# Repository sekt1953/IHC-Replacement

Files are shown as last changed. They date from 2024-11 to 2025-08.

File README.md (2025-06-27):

# IHC-Replacement

Her laver jeg en erstatning for mit LK IHC system

Jeg kan ikke længere få reserve dele til mit IHC system som styrer alt lys i huset. 
Jeg har i forevejen et Home Assistant project igang, så nu vil jeg fremstille PCB som kan virke som interface mellem min El installation Og Home Assistant.

## Fritzing

* I/O Ver. 0.22 FritzingFab
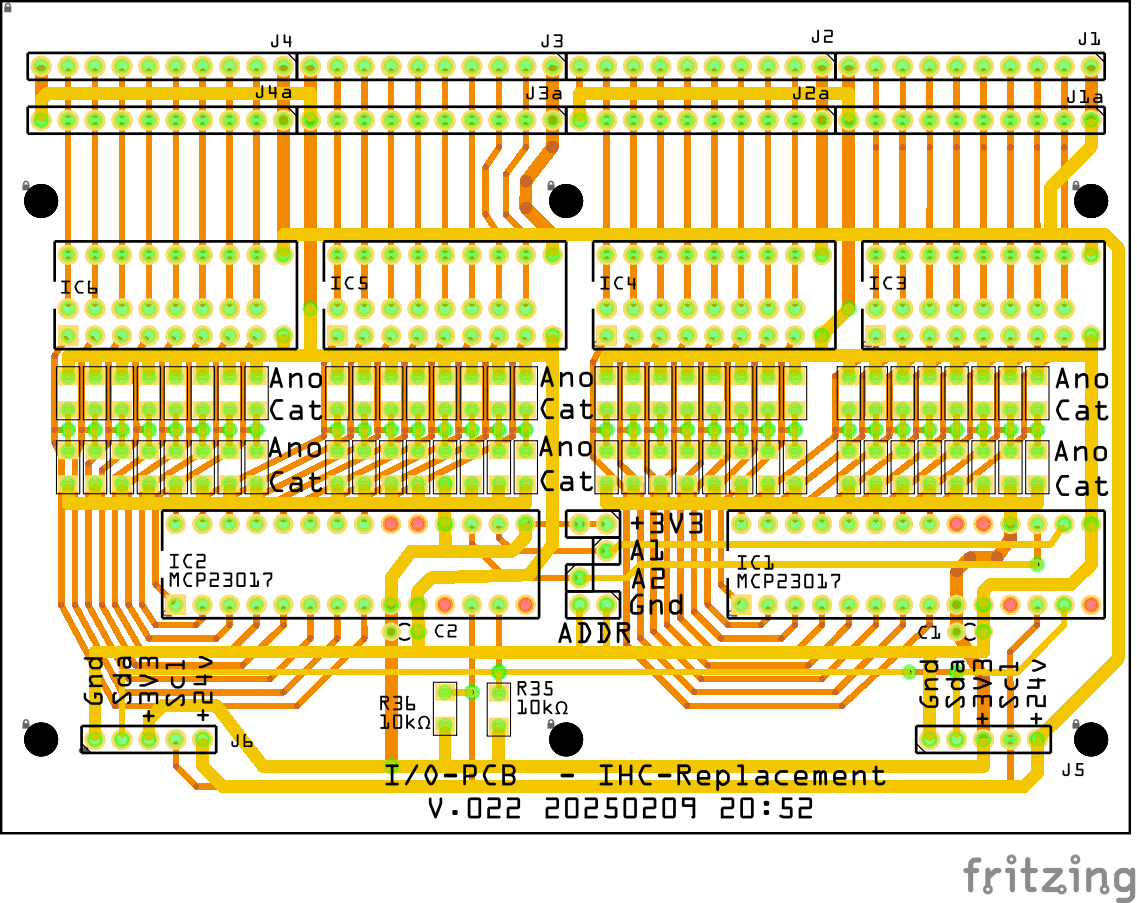
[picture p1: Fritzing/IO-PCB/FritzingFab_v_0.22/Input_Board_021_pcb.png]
PCB 0.22
  * 
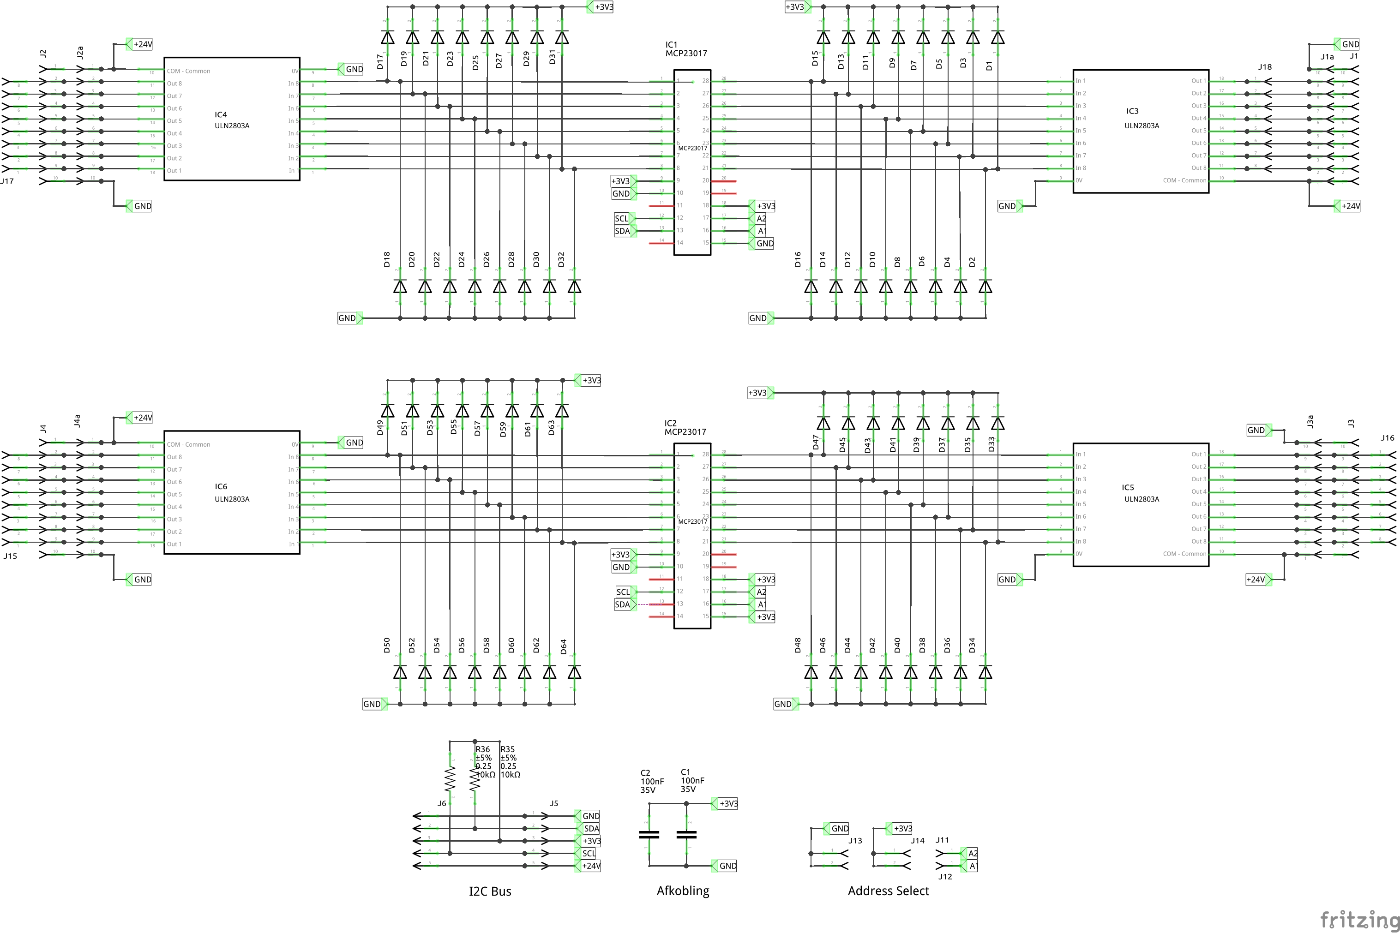
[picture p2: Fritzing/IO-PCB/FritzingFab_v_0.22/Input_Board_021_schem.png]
schem 0.22
  * 
  * [fzz 0.22](./Fritzing/IO-PCB/FritzingFab_v_0.22/Input_Board_022.fzz)
* I/O Ver. 0.41 
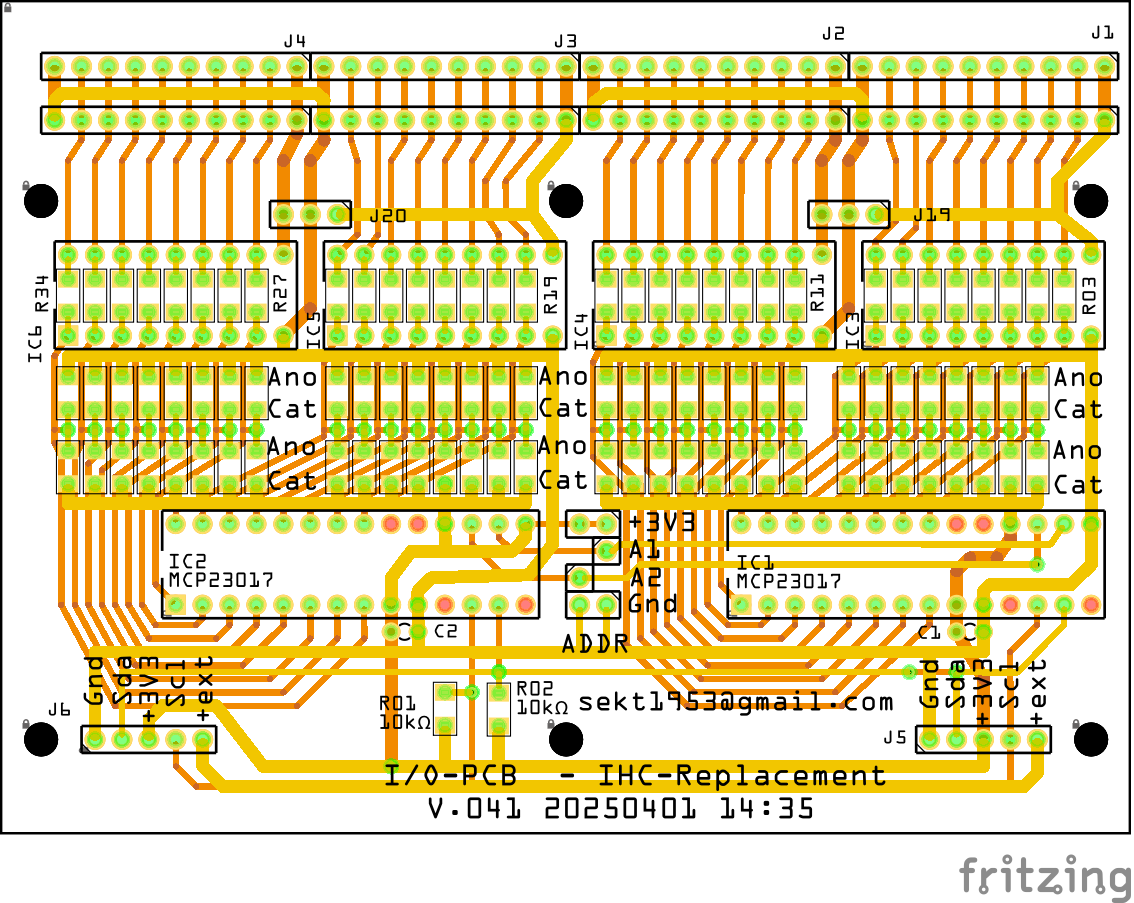
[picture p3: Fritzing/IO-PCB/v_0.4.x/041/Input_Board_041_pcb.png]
PCB 0.41
  * 
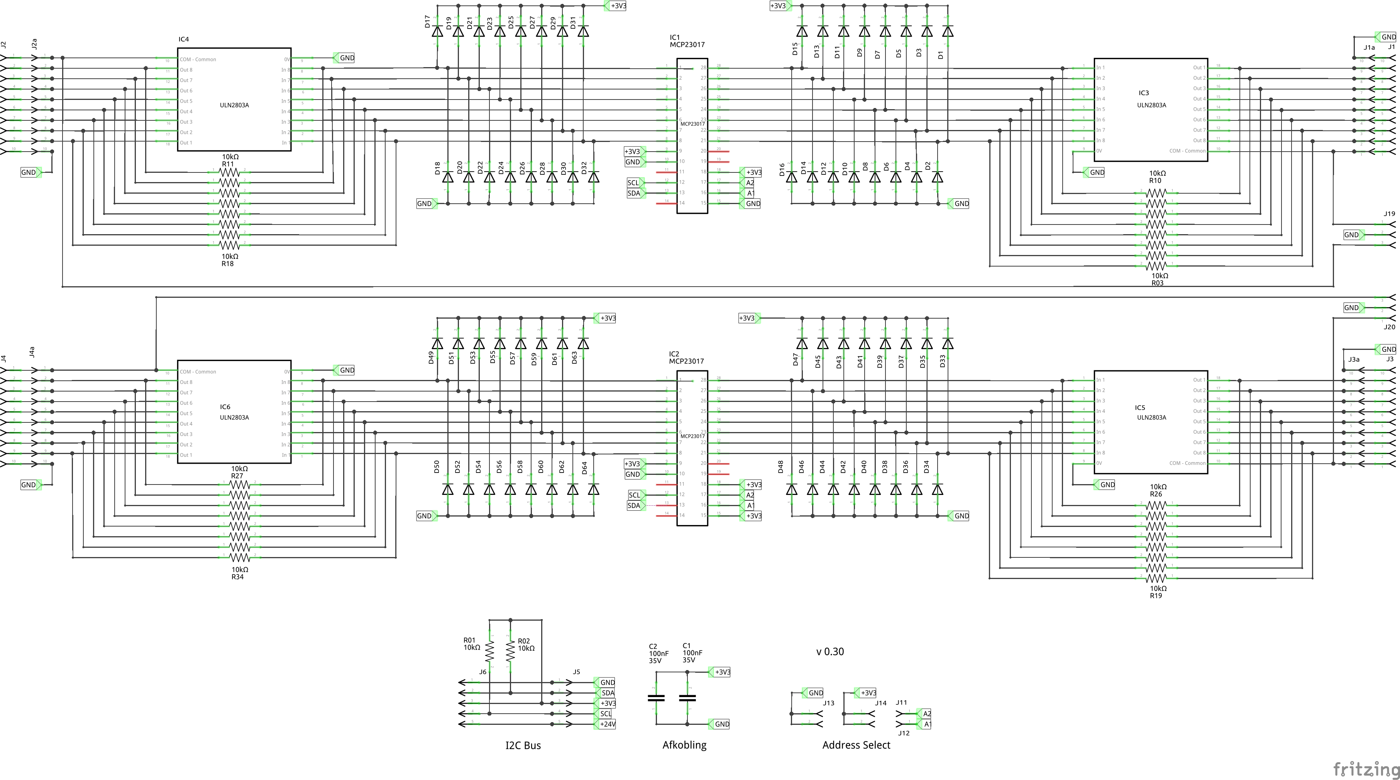
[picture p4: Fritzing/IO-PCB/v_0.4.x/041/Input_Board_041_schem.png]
schem 0.41
  * 
  * [Fritzing file version 0.41](./Fritzing/IO-PCB/v_0.4.x/041/Input_Board_041.fzz)

### Bill of Materials

* I/O-PCB IHC-Replacement v.041 20250401 17:51
  * Fælleds for Input og Output config
    * 1 stk PCB, I/O-PCB IHC-Replacement v.040
    * 2 stk MCP20017-E/SP 16-bit
    * 2 stk Ceramic Capacitor 100nF
    * 2 stk 10kΩ Resistor SMD 1206
    * 2 stk 5 pol connector for I2C bus, vinkel MOD 2,54mm
    * 4 stk 10 pol connector for Input / Output, KF141R-10P MOD 2,54mm
    * 2 stk jumper for I2C addr. settings
    * 1 Tube SMD Solder Paste Flux Low Temperature 138°C 30g
  * Matrialer for Input PCB
    * 64 stk 1N4148 SMD 1206
    * 32 stk 10kΩ Resistor SMD 1206
  * Matrialer for Output PCB
    * 4 stk ULN2803A
    * 2 stk 3pol connector for nødbelysning MOD 2,54mm

## FreeCAD

* [DINBox_200 FreeCAD-file](./FreeCAD/DinBox/DinBox_200/DinBox_200.FCStd)
* [DinBox_200_Top
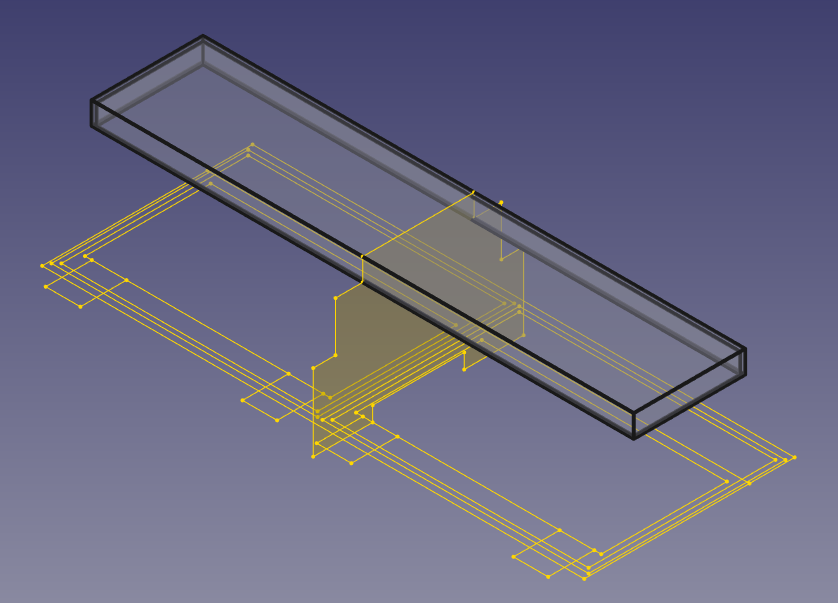
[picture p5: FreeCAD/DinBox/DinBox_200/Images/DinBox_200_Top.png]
DinBox_200_Top
  * 
* DinBox_200_Body
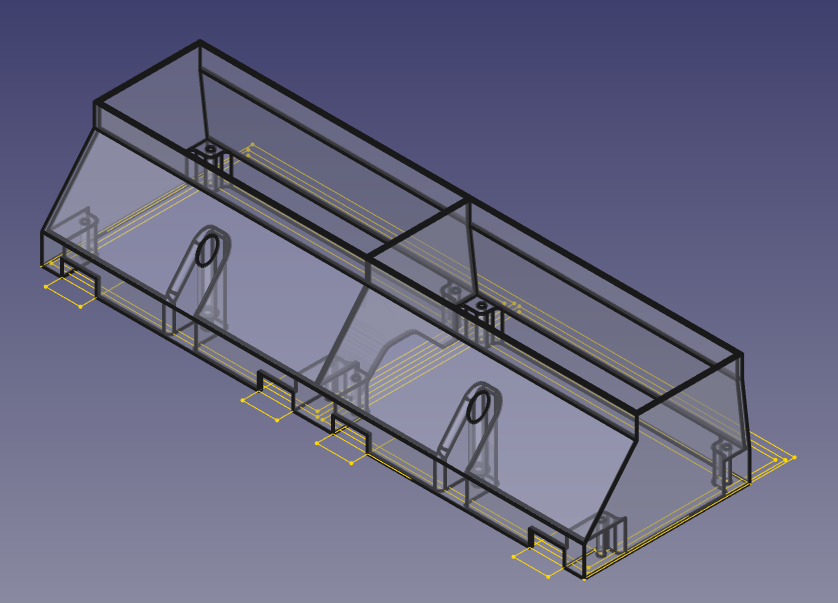
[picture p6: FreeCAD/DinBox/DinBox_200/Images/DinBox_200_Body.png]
DinBox_200_Body
  * 
* DinBox_200_BodyYZ
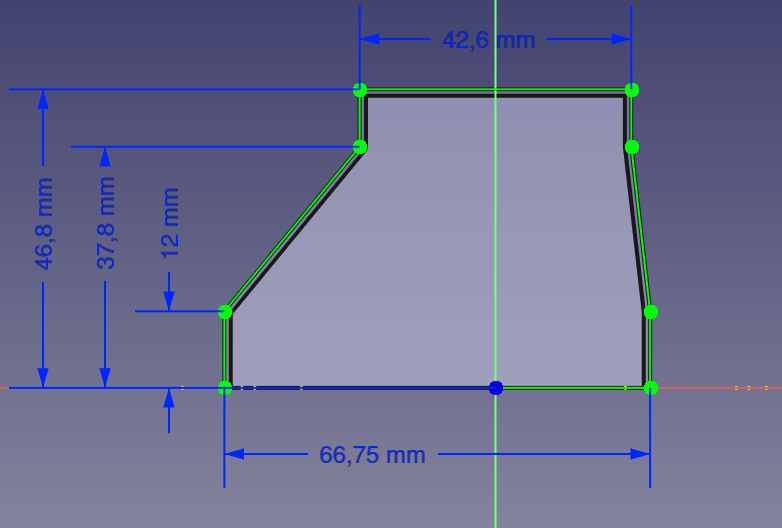
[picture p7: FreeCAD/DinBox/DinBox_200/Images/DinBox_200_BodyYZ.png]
DinBox_200_BodyYZ
  * 
* DinBox_200_BaseXY
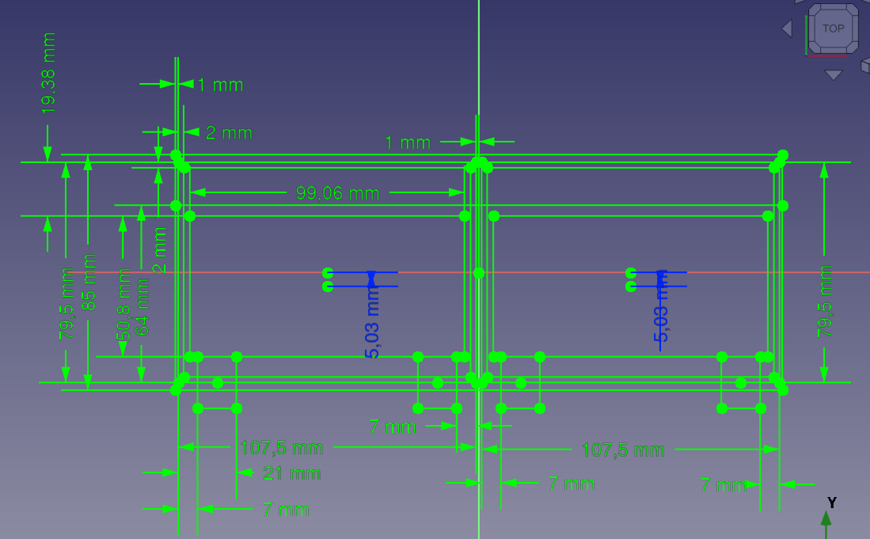
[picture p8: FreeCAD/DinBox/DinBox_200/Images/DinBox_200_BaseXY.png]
DinBox_200_BaseXY
  * 
* DinBox_200_BaseYZ
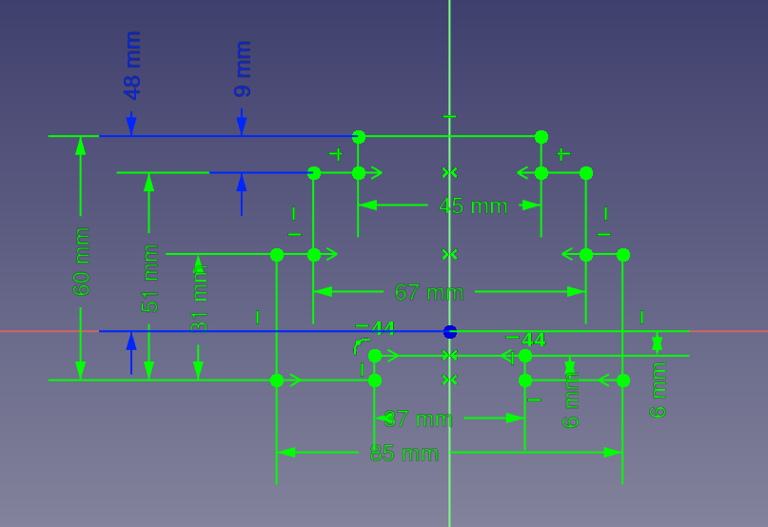
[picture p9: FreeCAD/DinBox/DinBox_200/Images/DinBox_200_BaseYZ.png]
DinBox_200_BaseYZ
  * 
* DINBox_200 3mf-file
  * [DINBox_200 Top 3mf-file](./FreeCAD/DinBox/DinBox_200/DinBox_200-Top.3mf)
  * [DINBox_200 Body 3mf-file](./FreeCAD/DinBox/DinBox_200/DinBox_200-Body002.3mf)

## Home Assistant

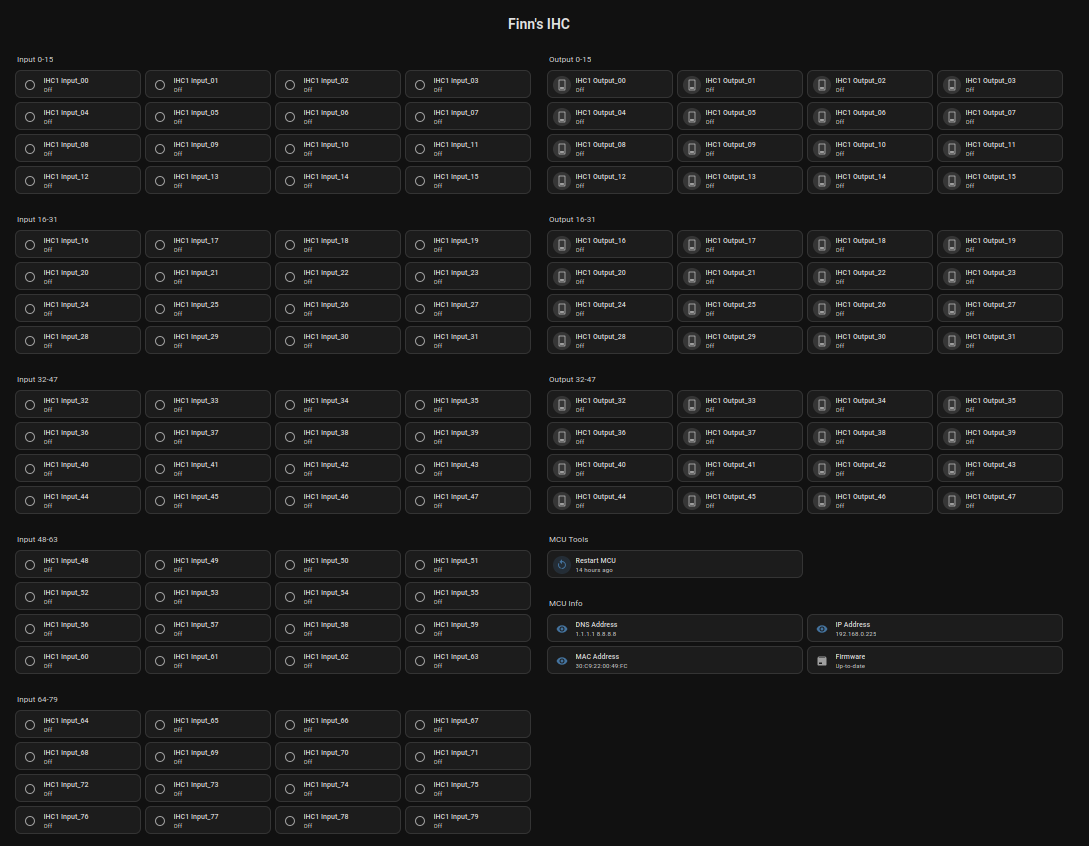
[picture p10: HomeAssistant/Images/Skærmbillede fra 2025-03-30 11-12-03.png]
Skærmbilled
* 
  * [Raw configuration Finn's IHC](./HomeAssistant/RawConfigurationFinnsIHC.yaml)

## ESPHome

### YAML-files

* Opsætningen her er for:
  * 48 output for relæer type [Finder](./DataSheet/Finder/Finder.md)
  * 80 input med transient beskyttelse.
* MCU: **OLIMEX ESP32-POE-ISO-16MB**
  * [Manual](./DataSheet/Olimex/ESP32-POE-user-manual.pdf)
  * [Pinout](./DataSheet/Olimex/ESP32-POE-ISO-GPIO.png)
  * **Basic file**
    * [ihc1.yaml](./ESPHome/ihc1.yaml)
  * ESP32 
    * [.olimex-esp32-poe.yaml](./ESPHome/Includes/ESP32/.olimex-esp32-poe.yaml)
  * MCP23017
    * [.mcp23017_ids.yaml](./ESPHome/Includes/MCP23017/.mcp23017_ids.yaml)
    * [.mcp23017_input.yaml](./ESPHome/Includes/MCP23017/.mcp23017_input.yaml)
    * [.mcp23017_output.yaml](./ESPHome/Includes/MCP23017/.mcp23017_output.yaml)
* Home Assistant
  * Automation
    * [LK-PushButton-Pressed](./HomeAssistant/LK-Button/LK-PushBUtton-Pressed.yaml)
      * [Long and short button pressing automation](https://community.home-assistant.io/t/long-and-short-button-pressing-automation/466916/6)
      * Array

Template editor:

```code
{% set my_test_json = { "items": ["car","horse"] } %}
* Items:{% for item in my_test_json["items"] %}
 * {{item}}
{%- endfor %}

* Items[0]:
* {{my_test_json["items"][0]}}

* Items[1]:
* {{my_test_json["items"][1]}}
```

Result:

```code
* Items:
  * car
  * horse

* Items[0]:
  * car

* Items[1]:
  * horse
```

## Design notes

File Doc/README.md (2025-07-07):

# Installations dokumentation

## Home Assistant & ESPHome

* [Home Assistant & ESPHome instllation](./LK_taster_Pir_Røgdetectors_kabling.md)
  * [Input - LK taster, Pir & Røgdetector's kabling](./LK_taster_Pir_Røgdetectors_kabling.md#input)
  * [Output - LK taster, Pir & Røgdetector's kabling](./LK_taster_Pir_Røgdetectors_kabling.md#output)

## ESP32

* Olimex
  * [ESP32-POE-ISO-16MB](https://www.olimex.com/Products/IoT/ESP32/ESP32-POE-ISO/open-source-hardware)
  * [ESP32-POE-ISO user manual](https://github.com/OLIMEX/ESP32-POE/blob/master/DOCUMENTS/ESP32-POE-user-manual.pdf)
  * [ESP32-POE-ISO latest schematic in PDF format](https://github.com/OLIMEX/ESP32-POE-ISO/blob/master/HARDWARE/ESP32-PoE-ISO-Rev.L/ESP32-PoE-ISO_Rev_L.pdf)
  * [ESP32-POE-ISO GPIO map](https://www.olimex.com/Products/IoT/ESP32/ESP32-POE-ISO/resources/ESP32-POE-ISO-GPIO.png)

## Zigbee

* [SilverCrest Zigbee Gateway](https://zigbee.blakadder.com/Lidl_TYGWZ-01.html)

## Tailscale

* Videoer
  * [Tailscale](https://www.youtube.com/@Tailscale)
    * [How to get started with Tailscale in under 10 minutes](https://youtu.be/sPdvyR7bLqI)
    * [Remotely access Home Assistant via Tailscale for free!](https://youtu.be/vDxmtRByXDY)
    * [Remotely access and share your self-hosted services](https://youtu.be/Vt4PDUXB_fg "Tailscale")
  * [Tailscale Explained](https://www.youtube.com/playlist?list=PLbKN2w7aG8ELRhEl3b-skkHxz6jcKLuFT)
    * [Serve and Funnel](https://youtu.be/MpxmfpCl20c?list=PLbKN2w7aG8ELRhEl3b-skkHxz6jcKLuFT)
    * [What is Tailscale SSH?](https://youtu.be/08clF9srJ2k?list=PLbKN2w7aG8ELRhEl3b-skkHxz6jcKLuFT)
      * [Tailscale SSH](https://tailscale.com/kb/1193/tailscale-ssh)
    * [Subnet Routers](https://youtu.be/UmVMaymH1-s?list=PLbKN2w7aG8ELRhEl3b-skkHxz6jcKLuFT)
    * [ACLs 101 - An Introduction to Access Control Lists](https://youtu.be/Jn8_Sh4r8d4?list=PLbKN2w7aG8ELRhEl3b-skkHxz6jcKLuFT)
      * [Manage permissions using ACLs](https://tailscale.com/kb/1018/acls)
    * [Exit Nodes](https://youtu.be/Ad7D2pkFNdA?list=PLbKN2w7aG8ELRhEl3b-skkHxz6jcKLuFT)
    * [App Connectors - Split DNS for any website on your tailnet ](https://youtu.be/z1vBMMQzCEk?list=PLbKN2w7aG8ELRhEl3b-skkHxz6jcKLuFT)

## IHC (gammel installation)

* [IHC (gammel installation)](./IHC_gammel%20installation.md)

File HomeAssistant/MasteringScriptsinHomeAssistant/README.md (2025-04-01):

# Mastering Scripts in Home Assistant

## Kilder:

* [Smart Home Junkie](https://www.youtube.com/@SmartHomeJunkie)
  * [Mastering Scripts in Home Assistant: A Comprehensive Guide](https://youtu.be/vD_xckjQxRk)
* [SlackerLabs](https://www.youtube.com/@SlackerLabs)
  * [Mastering Home Assistant Templates: Intro to Date and Time](https://youtu.be/2WIi5xq0iHI?list=PLJAP47iycH2IV8m5RnMF4hmZ_mVb7vgv_)

## Use Case 1: Send a fixed message to your phone

## Use Case 2: [Send a custom message to your phone using fields in scripts](https://www.youtube.com/watch?v=vD_xckjQxRk&t=219s)

* Script: "Notify: Persistent"

```code
sequence:
  - action: persistent_notification.create
    metadata: {}
    data:
      message: "{{message}}"
      title: "{{title}}"
alias: "Notify: Persistent"
description: 
fields:
  title:
    selector:
      text: null
    name: title
    description: Enter a title for your notification
    required: true
  message:
    selector:
      text: null
    name: message
    description: Enter a message for your notification
    required: true
```

* Automation: "Notify: Send a custom message"

```code
alias: "Notify: Send a custom message"
description: ""
triggers:
  - trigger: state
    entity_id:
      - binary_sensor.ihc1_input_00
      - binary_sensor.ihc1_input_02
    to: "on"
conditions: []
actions:
  - action: script.notify_persistent
    data:
      title: This is a custom title
      message: and this is the custom message
mode: single

```

## Use Case 3: [Send a custom weather condition to your phone using response variables in scripts](https://www.youtube.com/watch?v=vD_xckjQxRk&t=454s)

* Script: "Weather: get custom weather condition"

```code
alias: "Weather: get custom weather condition"
variables:
  weather_condition: |
    {% set temperature = state_attr("weather.forecast_hjem","temperature") %}
    {% if (temperature < 5) %}
      {% set condition = "Cold" %}
    {% elif (temperature >= 5 and temperature <= 15 ) %}
      {% set condition = "Chilly" %}
    {% elif (temperature >= 15 and temperature <= 20 ) %}
      {% set condition = "Comfortable" %}
    {% elif (temperature >= 20 and temperature <= 30 ) %}
      {% set condition = "Warm" %}
    {% elif (temperature >= 30 ) %}
      {% set condition = "To Warm !!" %}
    {% endif %}
    {{ {'value': condition} }}
sequence:
  - stop: End
    response_variable: weather_condition
description: ""
```

* Automation: ""

```code
alias: "Notify: Send a custom message"
description: ""
triggers:
  - trigger: state
    entity_id:
      - binary_sensor.ihc1_input_00
      - binary_sensor.ihc1_input_02
      - switch.ihc1_output_00
    to: "on"
    for:
      hours: 0
      minutes: 0
      seconds: 1
conditions: []
actions:
  - action: script.weather_get_custom_weather_condition
    data: {}
    response_variable: result
  - action: script.notify_persistent
    data:
      message: The weather is {{ result.value }}
      title: Weather Condition
mode: single

```

## Mastering Home Assistant Templates: Intro to Date and Time

[Mastering Home Assistant Templates: Intro to Date and Time](https://www.youtube.com/watch?v=2WIi5xq0iHI&list=PLJAP47iycH2IV8m5RnMF4hmZ_mVb7vgv_&index=3&t=1707s)

```code
{{ states.switch.ihc1_output_00.last_updated }}
{{ states.switch.ihc1_output_00.last_changed }}

{{ as_datetime('2024-03-20 12:04:20') }}
{{ as_timestamp('2024-03-20 12:04:20') }}
{{ as_timestamp('2024-03-20') }}

**
{{ 
  as_timestamp(now()) -
  as_timestamp(states.switch.ihc1_output_00.last_changed)
}}
```

## Call a Script from an Automation, and access Trigger/Entity inside the Script

### Kilde: [Call a Script from an Automation, and access Trigger/Entity inside the Script](https://community.home-assistant.io/t/call-a-script-from-an-automation-and-access-trigger-entity-inside-the-script/603114/2)

### You need to pass the trigger variables to the script: https://www.home-assistant.io/integrations/script/#passing-variables-to-scripts

* Automation:

```code
action:
  - service: script.notify_level1_user
    data:
      trig_id: "{{ trigger.entity_id }}"
      trig_val: "{{ trigger.to_state.state }}"
```

* And in the script

```code
sequence:
  - service: notify.level1_users # or whatever your notification service is called
    data:
      message: " The sensor {{ trig_id }} has the value {{ trig_val }}"
```
### Developer tools

* Kilde:
  * [Extract a nested array value in JSON](https://community.home-assistant.io/t/solved-extract-a-nested-array-value-in-json/173906/2)

#### Template editor

```yaml
"meta" : [ { 
    "publisher" : "Environment Agency" ,
    "licence" : "http://www.nationalarchives.gov.uk/doc/open-government-licence/version/3/" ,
    "documentation" : "http://environment.data.gov.uk/flood-monitoring/doc/reference" ,
    "version" : "0.9" ,
    "comment" : "Status: Beta service" ,
    "hasFormat" : [ { "csv" : "http://environment.data.gov.uk/flood-monitoring/id/stations/2077/readings.csv?latest", "rdf" : "http://environment.data.gov.uk/flood-monitoring/id/stations/2077/readings.rdf?latest" } ]
  } ],
  "items" : [ { 
    "@id" : "http://environment.data.gov.uk/flood-monitoring/data/readings/2077-level-stage-i-15_min-mASD/2020-02-23T11-00-00Z" ,
    "dateTime" : "2020-02-23T11:00:00Z" ,
    "measure" : "http://environment.data.gov.uk/flood-monitoring/id/measures/2077-level-stage-i-15_min-mASD" ,
    "value" : 3.518
  }
   ]
} %}
meta:
{{ value_json['meta'][0].publisher }}
{{ value_json['meta'][0].licence }}
{{ value_json['meta'][0].documentation }}
{{ value_json['meta'][0].version }}
{{ value_json['meta'][0].comment }}
{{ value_json['meta'][0].hasFormat[0].csv }}
{{ value_json['meta'][0].hasFormat[0].rdf }}

Items:
{{ value_json['items'][0].id }}
{{ value_json['items'][0].dateTime }}
{{ value_json['items'][0].measure }}
{{ value_json['items'][0].value }}
```

#### Result

```yaml
meta:
Environment Agency
http://www.nationalarchives.gov.uk/doc/open-government-licence/version/3/
http://environment.data.gov.uk/flood-monitoring/doc/reference
0.9
Status: Beta service
http://environment.data.gov.uk/flood-monitoring/id/stations/2077/readings.csv?latest
http://environment.data.gov.uk/flood-monitoring/id/stations/2077/readings.rdf?latest

Items:
http://environment.data.gov.uk/flood-monitoring/data/readings/2077-level-stage-i-15_min-mASD/2020-02-23T11-00-00Z
2020-02-23T11:00:00Z
http://environment.data.gov.uk/flood-monitoring/id/measures/2077-level-stage-i-15_min-mASD
3.518
```

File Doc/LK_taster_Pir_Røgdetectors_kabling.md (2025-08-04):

# LK taster, Pir & Røgdetector's kabling

## Input

|Kabel|Lokalitet|Placering____|Komponent|Terminal|Farve|I/O Interface|I2C-Addr|Kort_Tryk|Langt_Tryk||
|:---:|:---|:---|:---|:---:|:---|:---|:---|:---|:---|:---|
|1|Lille Bad|Ved dør|Tryk 4 tast|GND|Blå|GND|||
|1|Lille Bad|Ved dør|Tryk 4 tast|Tryk ØV|Sort|Input_00|0x23.0|Output_34|Output_34||
|1|Lille Bad|Ved dør|Tryk 4 tast|Tryk ØH|Grøn|Input_01|0x23.1|Output_05|||
|1|Lille Bad|Ved dør|Tryk 4 tast|Tryk NV|Violet|Input_02|0x23.2|Output_32|||
|1|Lille Bad|Ved dør|Tryk 4 tast|Tryk NH|Brun|Input_03|0x23.3|Output_06|||
||||||||||
|2|Kontor|Ved dør|Tryk 4 tast|GND|Blå|GND|||
|2|Kontor|Ved dør|Tryk 4 tast|Tryk ØV|Sort|Input_04|0x23.4|Output_26|Output_26||
|2|Kontor|Ved dør|Tryk 4 tast|Tryk ØH|Grøn|Input_05|0x23.5||||
|2|Kontor|Ved dør|Tryk 4 tast|Tryk NV|Violet|Input_06|0x23.6||||
|2|Kontor|Ved dør|Tryk 4 tast|Tryk NH|Brun|Input_07|0x23.7||||
||||||||||
|3|Værelse|Ved dør|Tryk 4 tast|GND|Blå|GND|||
|3|Værelse|Ved dør|Tryk 4 tast|Tryk ØV|Sort|Input_08|0x23.8|Output_27|Output_27||
|3|Værelse|Ved dør|Tryk 4 tast|Tryk ØH|Grøn|Input_09|0x23.9||
|3|Værelse|Ved dør|Tryk 4 tast|Tryk NV|Violet|Input_10|0x23.10||
|3|Værelse|Ved dør|Tryk 4 tast|Tryk NH|Brun|Input_11|0x23.11||
||||||||||
|9|Soveværelse|Ved seng V|Tryk 4 tast|GND|Blå|GND|||
|9|Soveværelse|Ved seng V|Tryk 4 tast|Tryk ØV|Sort|Input_12|0x23.12||||
|9|Soveværelse|Ved seng V|Tryk 4 tast|Tryk ØH|Grøn|Input_13|0x23.13|Output_12|||
|9|Soveværelse|Ved seng V|Tryk 4 tast|Tryk NV|Violet|Input_14|0x23.14|Output_17|||
|9|Soveværelse|Ved seng V|Tryk 4 tast|Tryk NH|Brun|Input_15|0x23.15||||
||||||||||
||||||||||
|4|Garage|Bryggers dør|Tryk 6 tast|GND|Blå|GND|||||
|4|Garage|Bryggers dør|Tryk 6 tast|Tryk ØV|Sort|Input_16|0x24.0||||
|4|Garage|Bryggers dør|Tryk 6 tast|Tryk ØH|Grøn|Input_17|0x24.1||||
|4|Garage|Bryggers dør|Tryk 6 tast|Tryk MV|Violet|Input_18|0x24.2||||
|4|Garage|Bryggers dør|Tryk 6 tast|Tryk MH|Brun|Input_19|0x24.3||
|4|Garage|Bryggers dør|Tryk 6 tast|Tryk NV|Rød|Input_20|0x24.4||
|4|Garage|Bryggers dør|Tryk 6 tast|Tryk NH|Grå|Input_21|0x24.5||
||||||||||
|5|Køkken|Bryggers dør|Tryk 6 tast|GND|Blå|GND|||
|5|Køkken|Bryggers dør|Tryk 6 tast|Tryk ØV|Sort|Input_22|0x24.6||
|5|Køkken|Bryggers dør|Tryk 6 tast|Tryk ØH|Grøn|Input_23|0x24.7||
|5|Køkken|Bryggers dør|Tryk 6 tast|Tryk MV|Violet|Input_24|0x24.8||
|5|Køkken|Bryggers dør|Tryk 6 tast|Tryk MH|Brun|Input_25|0x24.9||
|5|Køkken|Bryggers dør|Tryk 6 tast|Tryk NV|Rød|Input_26|0x24.10||
|5|Køkken|Bryggers dør|Tryk 6 tast|Tryk NH|Grå|Input_27|0x24.11||
||||||||||
||||||||||
|6|Stue|På væg|Tryk 6 tast|GND|Blå|GND|||
|6|Stue|På væg|Tryk 6 tast|Tryk ØV|Sort|Input_32|0x25.0||
|6|Stue|På væg|Tryk 6 tast|Tryk ØH|Grøn|Input_33|0x25.1||
|6|Stue|På væg|Tryk 6 tast|Tryk MV|Violet|Input_34|0x25.2||
|6|Stue|På væg|Tryk 6 tast|Tryk MH|Brun|Input_35|0x25.3||
|6|Stue|På væg|Tryk 6 tast|Tryk NV|Rød|Input_36|0x25.4||
|6|Stue|På væg|Tryk 6 tast|Tryk NH|Grå|Input_37|0x25.5||
||||||||||
|7|Entré|Køkken dør|Tryk 6 tast|GND|Blå|GND|||
|7|Entré|Køkken dør|Tryk 6 tast|Tryk ØV|Sort|Input_38|0x25.6||
|7|Entré|Køkken dør|Tryk 6 tast|Tryk ØH|Grøn|Input_39|0x25.7||
|7|Entré|Køkken dør|Tryk 6 tast|Tryk MV|Violet|Input_40|0x25.8||
|7|Entré|Køkken dør|Tryk 6 tast|Tryk MH|Brun|Input_41|0x25.9||
|7|Entré|Køkken dør|Tryk 6 tast|Tryk NV|Rød|Input_42|0x25.10||
|7|Entré|Køkken dør|Tryk 6 tast|Tryk NH||Input_43|0x25.11||
||||||||||
|10|Entré|Yderdør|Tryk 4 tast|GND|Blå|GND|||
|10|Entré|Yderdør|Tryk 4 tast|Tryk ØV|Sort|Input_44|0x25.12||
|10|Entré|Yderdør|Tryk 4 tast|Tryk ØH|Grøn|Input_45|0x25.13||
|10|Entré|Yderdør|Tryk 4 tast|Tryk NV|Violet|Input_46|0x25.14||
|10|Entré|Yderdør|Tryk 4 tast|Tryk NH||Input_47|0x25.15||
||||||||||
||||||||||
|8|Soveværelse|St. bad|Tryk 6 tast|GND|Blå|GND|||
|8|Soveværelse|St. bad|Tryk 6 tast|Tryk ØV|Sort|Input_48|0x26.0||
|8|Soveværelse|St. bad|Tryk 6 tast|Tryk ØH|Grøn|Input_49|0x26.1||
|8|Soveværelse|St. bad|Tryk 6 tast|Tryk MV|Violet|Input_50|0x26.2||
|8|Soveværelse|St. bad|Tryk 6 tast|Tryk MH|Brun|Input_51|0x26.3||
|8|Soveværelse|St. bad|Tryk 6 tast|Tryk NV|Rød|Input_52|0x26.4||
|8|Soveværelse|St. bad|Tryk 6 tast|Tryk NH|Grå|Input_53|0x26.5||
||||||||||
|11|Køkken|Viktualrum|Tryk 6 tast|GND|Blå|GND|||
|11|Køkken|Viktualrum|Tryk 6 tast|Tryk ØV|Sort|Input_54|0x26.6||
|11|Køkken|Viktualrum|Tryk 6 tast|Tryk ØH|Grøn|Input_55|0x26.7||
|11|Køkken|Viktualrum|Tryk 6 tast|Tryk MV|Violet|Input_56|0x26.8||
|11|Køkken|Viktualrum|Tryk 6 tast|Tryk MH|Brun|Input_57|0x26.9||
|11|Køkken|Viktualrum|Tryk 6 tast|Tryk NV|Rød|Input_58|0x26.10||
|11|Køkken|Viktualrum|Tryk 6 tast|Tryk NH|Grå|Input_59|0x26.11||
||||||||||
|33|Stue|På væg|Pir|Alarm|Sort|Input_60|0x26.12||
||Soveværelse|Ved dør til toilet|Pir|Alarm|Hvid|Input_61|0x26.13||
|31|Bryggers|På væg|Pir|Alarm|Sort|Input_62|0x26.14||
|30|Garage|På væg|Pir|Alarm|Sort|Input_63|0x26.15||
||||||||||
||||||||||
|12|Garage|Yderdør|Tryk 6 tast|GND|Blå|GND|||
|12|Garage|Yderdør|Tryk 6 tast|Tryk ØV|Sort|Input_64|0x27.0||
|12|Garage|Yderdør|Tryk 6 tast|Tryk ØH|Grøn|Input_65|0x27.1||
|12|Garage|Yderdør|Tryk 6 tast|Tryk MV|Violet|Input_66|0x27.2||
|12|Garage|Yderdør|Tryk 6 tast|Tryk MH|Brun|Input_67|0x27.3||
|12|Garage|Yderdør|Tryk 6 tast|Tryk NV|Rød|Input_68|0x27.4||
|12|Garage|Yderdør|Tryk 6 tast|Tryk NH|Grå|Input_69|0x27.5||
||||||||||
||Stue||Røgsensor||Orange|Input_70|0x27.6|
||Soveværelse||Røgsensor||Hvid|Input_71|0x27.7||
|36|Bryggers|I loft|Røgsensor||Sort|Input_72|0x27.8|Udgang 7|02|Violet|
||Garage||Røgsensor|||Input_73|0x27.9||Udgang 7|02||
||Udendørs|Indkørsel|Røgsensor||Grøn|Input_74|0x27.10|Udgang 7|03|HvidBlå|
||||||||||||
||||||||||||
|9|Soveværelse|Ved seng H|Tryk 4 tast|GND|Grå|GND|||||
|9|Soveværelse|Ved seng H|Tryk 4 tast|Tryk ØV|Rød|Input_76|0x27.12||||
|9|Soveværelse|Ved seng H|Tryk 4 tast|Tryk ØH|Hvid|Input_77|0x27.13||||
|9|Soveværelse|Ved seng H|Tryk 4 tast|Tryk NV|Orange|Input_78|0x27.14||||
|9|Soveværelse|Ved seng H|Tryk 4 tast|Tryk NH|Gul|Input_79|0x27.15||||
||||||||||||

## Output

### Relæ 220VAC

||Lokalitet|Placering|Relæ||||IHC Modul|I/O Interface|I2C-Addr|
|---:|:---|:---|:---:|:---:|:---:|:---:|:---:|:---:|:---:|
|0|Køkken|Spisebord|||||IHC1|Output_00|0x20.0|
|1|||||||IHC1|Output_01|0x20.1|
|2|Udelys|Hæk|||||IHC1|Output_02|0x20.2|
|3|Køkken|Spot|||||IHC1|Output_03|0x20.3|
|4|Stue|Spot|||||IHC1|Output_04|0x20.4|
|5|LilleBad|Spot|||||IHC1|Output_05|0x20.5|
|6|Bryggers|Spot|||||IHC1|Output_06|0x20.6|
|7|Stort Bad|Spot|||||IHC1|Output_07|0x20.7|
|8|||||||IHC1|Output_08|0x20.8|
|9|||||||IHC1|Output_09|0x20.9|
|10|Udelys||||||IHC1|Output_10|0x20.10|
|11|||||||IHC1|Output_11|0x20.11|
|12|Stort Bad|Spejl|||||IHC1|Output_12|0x20.12|
|13|||||||IHC1|Output_13|0x20.13|
|14|||||||IHC1|Output_14|0x20.14|
|15|||||||IHC1|Output_15|0x20.15|
|16|Soveværelse|Loft|||||IHC1|Output_16|0x21.0|
|17|WalkIn|Loft|||||IHC1|Output_17|0x21.1|
|18|Entre||||||IHC1|Output_18|0x21.2|
|19|Stue|Sofabord|||||IHC1|Output_19|0x21.3|
|20|Køkken|Bord|||||IHC1|Output_20|0x21.4|
|21|||||||IHC1|Output_21|0x21.5|
|22|||||||IHC1|Output_22|0x21.6|
|23|||||||IHC1|Output_23|0x21.7|
|24|||||||IHC1|Output_24|0x21.8|
|25|Garage|Nord|||||IHC1|Output_25|0x21.9|
|26|Kontor|Loft|||||IHC1|Output_26|0x21.10|
|27|Værelse|Loft|||||IHC1|Output_27|0x21.11|
|28|Garage|Syd|||||IHC1|Output_28|0x21.12|
|29|||||||IHC1|Output_29|0x21.13|
|30||Stikkontakt|||||IHC1|Output_30|0x21.14|
|31|||||||IHC1|Output_31|0x21.15|
|32|Bryggers|Bord|||||IHC1|Output_32|0x22.0|
|33|Spisekammer|loft|||||IHC1|Output_33|0x22.1|
|34|Lille Bad|Spejl|||||IHC1|Output_34|0x22.2|
|35|||||||IHC1|Output_35|0x22.3|
|36|||||||IHC1|Output_36|0x22.4|
|37|||||||IHC1|Output_37|0x22.5|
|38|||||||IHC1|Output_38|0x22.6|
|39|||||||IHC1|Output_39|0x22.7|
|40|||||||IHC1|Output_40|0x22.8|
|41|||||||IHC1|Output_41|0x22.9|
|42|||||||IHC1|Output_42|0x22.10|
|43|||||||IHC1|Output_43|0x22.11|
|44|||||||IHC1|Output_44|0x22.12|
|45|||||||IHC1|Output_45|0x22.13|
|46|||||||IHC1|Output_46|0x22.14|
|47|||||||IHC1|Output_47|0x22.15|

## Helpers

|Nr.|Type|Name|Entity_ID|
|---:|:---:|:---:|:---:|
|1|Switch||
|2|Switch||
|3|Switch||
|4|Switch||
|5|Switch||
|6|Switch||
|7|Switch||
|8|Switch||
|9|Switch||
|10|Switch||

<HR>
### Gammel installation

||Lokalitet|Placering|Komponent|Farve|Kabel|Kabeltype|IHC Modul|Adresse|Ledning|
|:---:|:---:|:---:|:---:|:---:|:---:|:---:|:---:|:---:|:---:|
|0|Stue|Spot|Lampeudtag|--|208|2x4+2x1.5|Udgang 8|04|Sort|
|1|Stue|I loft|Lampeudtag|Hvid|211|5x1.5|Udgang 4|05|Hvid|
|2|Stue|I kip|Lampeudtag|Sort|205|5x1.5|Udgang 4|02|Sort|
|3|Stue|TV|Lampeudtag|Hvid|205|5x1.5|Udgang 4|03|Hvid|
|4|Stue|Gulv|Stikkontakt|Brun|103|5x1.5|Udgang 1|07|Brun|
|||||||||||
|5|Entré|I loft|Lampeudtag|Brun|206|5x1.5|Udgang 4|06|Brun|
|6|Entré|Gulv|Stikkontakt|Hvid|102|5x1.5|Udgang 2|03|Hvid|
|||||||||||
|7|Køkken|Spot|Lampeudtag|--|209|2x1.5|Udgang 8|05|Violet|
|8|Køkken|I loft|Lampeudtag|Sort|205|5x1.5|Udgang 4|04|Sort|
|9|Køkken|Over spisebord (gl. lysdæmp D12)|Lampeudtag|Brun|205|5x1.5|Udgang 8|08|Brun|
|10|Køkken|I kip D13|Lampeudtag|Brun|205|5x1.5|Udgang 6|03|Violet|
|11|Køkken|Gulv|Stikkontakt|Hvid|101 / 102|5x1.5|Udgang 1|03|Hvid|
|||||||||||
|12|Soveværelse|I loft|Lampeudtag|Hvid|206|5x1.5|Udgang 4|08|Hvid|
|13|Soveværelse|Gulv|Stikkontakt|Sort|103|5x1.5|Udgang 1|08|Sort|
|14|Soveværelse|TV|Stikkontakt|Hvid|207|5x1.5|Udgang 5|03|Hvid|
|||||||||||
|15|Værelse(8)|I loft|Lampeudtag|Sort|201|5x1.5|Udgang 3|04|Sort|
|16|Værelse(8)|Gulv|Stikkontakt|Brun|101 / 104|5x1.5|Udgang 1|04|Brun|
|||||||||||
|17|Værelse(2)|I loft|Lampeudtag|Hvid|201|5x1.5|Udgang 3|05|Hvid|
|18|Værelse(2)|Gulv|Stikkontakt|Brun|101|5x1.5|Udgang 1|01|Brun|
|||||||||||
|19|Stort Bad|I loft|Lampeudtag|Brun|207|5x1.5|Udgang 5|01|Brun|
|20|Stort Bad|Spot|Lampeudtag|--|210|2x4+2x1.5|Udgang 8|01|Brun|
|21|Stort Bad|Gulv|Stikkontakt|Sort|207|5x1.5|Udgang 5|02|Sort|
|||||||||||
|22|Bryggers|Spot|Lampeudtag|--|202|2x1.5|Udgang 8|02|Brun|
|23|Bryggers|På væg|Lampeudtag|Hvid|204|5x1.5|Udgang 2|07|Hvid|
|24|Bryggers|Gulv|Stikkontakt|Sort|101 / 204|5x1.5|Udgang 1|02|Sort|
|||||||||||
|25|Lille Bad|Spot|Lampeudtag|--|203|2x1.5|Udgang 8|03|Brun|
|26|Lille Bad|På væg|Lampeudtag|Brun|107|5x1.5|Udgang 2|04|Brun|
|27|Lille Bad|Gulv|Stikkontakt|Sort|107|5x1.5|Udgang 2|05|Sort|
|||||||||||
|28|Garage|I loft|Lampeudtag|Sort|200|5x1.5|Udgang 3|06|Sort|
|29|Garage|I loft|Lampeudtag|Hvid|200|5x1.5|Udgang 3|07|Hvid|
|30|Garage|I loft Ex|Lampeudtag|Brun|201|5x1.5|Udgang 3|03|Brun|
|31|Garage|Gulv|Stikkontakt|Hvid|100|5x1.5|Udgang 1|06|Hvid|
|32|Garage|Gulv Ex|Stikkontakt|Sort|100|5x1.5|Udgang 1|05|Sort|
|||||||||||
|33|Viktualrum|I loft|Lampeudtag|Brun|204|5x1.5|Udgang 2|06|Brun|
|34|Viktualrum|Gulv|Stikkontakt|Brun|102|5x1.5|Udgang 2|02|Brun|
|||||||||||
|35|Walkin|I loft|Lampeudtag|Sort|206|5x1.5|Udgang 4|07|Sort|
|36|Walkin|Gulv|Stikkontakt|Hvid|103|5x1.5|Udgang 2|01|Hvid|
|37|Walkin|Medie Center|Stikkontakt|Sort|213|5x1.5|Udgang 2|08|Sort|
|||||||||||
|38|Udendørs|På væg udv|Lampeudtag|Brun|212|3x1.5|Udgang 5|04|Brun|
|39|Udendørs|Spot|Lampeudtag|Hvid|107|5x1.5|Udgang 5|06|Hvid|
|40|Udendørs|Stikk ter.|Stikkontakt|Brun|105|5x1.5|Udgang 3|01|Brun|
|41|Udendørs|Stikk gar.|Stikkontakt|Brun|106|5x1.5|Udgang 3|02|Brun|
|42|Udendørs|I Jord Udvendig|Lampeudtag|Brun|--|5x1.5|Udgang 8|06|Brun|
|||||||||||
|43|Loft|I loft|Lampeudtag|Sort|107|5x1.5|Udgang 5|05|Sort|
|44|Loft|Dobbeltstik|Stikkontakt|--|--|5x1.5|Udgang 3|08|Sort|
|||||||||||
|45|Sluk Alt|Spot køk+stue|Lampeudtag|--|--|--|Udgang 6|02|Grøn|
|46|Magnetventil|--|Magnetventil NO|--|--|--|Udgang 8|07|Brun|
|||||||||||
|47|Køkken|Viktualrum|Lydgiver intern 80 dB|--|38|IHC LINK-10 NOPOVIC (5x2x0 6mm)|Udgang 6|05| Sort|
|48|Køkken|Viktualrum|Lydgiver intern 102 dB|--|38|IHC LINK-10 NOPOVIC (5x2x0 6mm)|Udgang 6|06|Grøn|
|49|Soveværelse|Diode|Lampeudtag|Gul|8|IHC LINK-10 NOPOVIC (5x2x0 6mm)|Udgang 7|04|Gul|
|50|Garage|Diode|Dørlås|--|--|IHC LINK-10 NOPOVIC (5x2x0 6mm)|Udgang 7|01|Orange|
|51|Udendørs|På væg udv|Lydgiver ekstern|Sort|39|IHC LINK-10 NOPOVIC (5x2x0 6mm)|Udgang 6|04|Sort|

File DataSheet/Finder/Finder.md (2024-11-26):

# Finder Relay for 220V interface

* Finder Relay
  * [Socket Type : 93.01.0.024](./1468426.pdf)
  * [Relay Type: 34.51.7.024.0010](./0900766b816d4f37.pdf)

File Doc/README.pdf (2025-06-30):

README.md | 2025-06-30

# Installations dokumentation

## Home Assistant & ESPHome instllation

Input - LK taster, Pir & Røgdetector's kabling

Kabel | Lokalitet | Placering____******* | Komponent | Terminal | Farve | I/O Interface | I2C- Addr
1 | Lille Bad | Ved dør | Tryk 4 tast | GND | Blå | GND
1 | Lille Bad | Ved dør | Tryk 4 tast | Tryk ØV | Sort | Input_00 | 0x23.0
1 | Lille Bad | Ved dør | Tryk 4 tast | Tryk ØH | Grøn | Input_01 | 0x23.1
1 | Lille Bad | Ved dør | Tryk 4 tast | Tryk NV | Violet | Input_02 | 0x23.2
1 | Lille Bad | Ved dør | Tryk 4 tast | Tryk NH | Brun | Input_03 | 0x23.3
2 | Kontor | Ved dør | Tryk 4 tast | GND | Blå | GND
2 | Kontor | Ved dør | Tryk 4 tast | Tryk ØV | Sort | Input_04 | 0x23.4
2 | Kontor | Ved dør | Tryk 4 tast | Tryk ØH | Grøn | Input_05 | 0x23.5
2 | Kontor | Ved dør | Tryk 4 tast | Tryk NV | Violet | Input_06 | 0x23.6
2 | Kontor | Ved dør | Tryk 4 tast | Tryk NH | Brun | Input_07 | 0x23.7
3 | Gæsteværelse | Ved dør | Tryk 4 tast | GND | Blå | GND
3 | Gæsteværelse | Ved dør | Tryk 4 tast | Tryk ØV | Sort | Input_08 | 0x23.8
3 | Gæsteværelse | Ved dør | Tryk 4 tast | Tryk ØH | Grøn | Input_09 | 0x23.9
3 | Gæsteværelse | Ved dør | Tryk 4 tast | Tryk NV | Violet | Input_10 | 0x23.10
3 | Gæsteværelse | Ved dør | Tryk 4 tast | Tryk NH | Brun | Input_11 | 0x23.11
9 | Soveværelse | Ved seng V | Tryk 4 tast | GND | Blå | GND
9 | Soveværelse | Ved seng V | Tryk 4 tast | Tryk ØV | Sort | Input_12 | 0x23.12
9 | Soveværelse | Ved seng V | Tryk 4 tast | Tryk ØH | Grøn | Input_13 | 0x23.13
9 | Soveværelse | Ved seng V | Tryk 4 tast | Tryk NV | Violet | Input_14 | 0x23.14
9 | Soveværelse | Ved seng V | Tryk 4 tast | Tryk NH | Brun | Input_15 | 0x23.15
4 | Garage | Ved bryggers dør | Tryk 6 tast | GND | Blå | GND
4 | Garage | Ved bryggers dør | Tryk 6 tast | Tryk ØV | Sort | Input_16 | 0x24.0
4 | Garage | Ved bryggers dør | Tryk 6 tast | Tryk ØH | Grøn | Input_17 | 0x24.1
4 | Garage | Ved bryggers dør | Tryk 6 tast | Tryk MV | Violet | Input_18 | 0x24.2
4 | Garage | Ved bryggers dør | Tryk 6 tast | Tryk MH | Brun | Input_19 | 0x24.3
4 | Garage | Ved bryggers dør | Tryk 6 tast | Tryk NV | Rød | Input_20 | 0x24.4
4 | Garage | Ved bryggers dør | Tryk 6 tast | Tryk NH | Grå | Input_21 | 0x24.5
5 | Køkken | Ved bryggers dør | Tryk 6 tast | GND | Blå | GND
5 | Køkken | Ved bryggers dør | Tryk 6 tast | Tryk ØV | Sort | Input_22 | 0x24.6
5 | Køkken | Ved bryggers dør | Tryk 6 tast | Tryk ØH | Grøn | Input_23 | 0x24.7
5 | Køkken | Ved bryggers dør | Tryk 6 tast | Tryk MV | Violet | Input_24 | 0x24.8
5 | Køkken | Ved bryggers dør | Tryk 6 tast | Tryk MH | Brun | Input_25 | 0x24.9
5 | Køkken | Ved bryggers dør | Tryk 6 tast | Tryk NV | Rød | Input_26 | 0x24.10

Kabel | Lokalitet | Placering____******* | Komponent | Terminal | Farve | I/O Interface | I2C- Addr
5 | Køkken | Ved bryggers dør | Tryk 6 tast | Tryk NH | Grå | Input_27 | 0x24.11
6 | Stue | På væg | Tryk 6 tast | GND | Blå | GND
6 | Stue | På væg | Tryk 6 tast | Tryk ØV | Sort | Input_32 | 0x25.0
6 | Stue | På væg | Tryk 6 tast | Tryk ØH | Grøn | Input_33 | 0x25.1
6 | Stue | På væg | Tryk 6 tast | Tryk MV | Violet | Input_34 | 0x25.2
6 | Stue | På væg | Tryk 6 tast | Tryk MH | Brun | Input_35 | 0x25.3
6 | Stue | På væg | Tryk 6 tast | Tryk NV | Rød | Input_36 | 0x25.4
6 | Stue | På væg | Tryk 6 tast | Tryk NH | Grå | Input_37 | 0x25.5
7 | Entré | Ved dør til køkken | Tryk 6 tast | GND | Blå | GND
7 | Entré | Ved dør til køkken | Tryk 6 tast | Tryk ØV | Sort | Input_38 | 0x25.6
7 | Entré | Ved dør til køkken | Tryk 6 tast | Tryk ØH | Grøn | Input_39 | 0x25.7
7 | Entré | Ved dør til køkken | Tryk 6 tast | Tryk MV | Violet | Input_40 | 0x25.8
7 | Entré | Ved dør til køkken | Tryk 6 tast | Tryk MH | Brun | Input_41 | 0x25.9
7 | Entré | Ved dør til køkken | Tryk 6 tast | Tryk NV | Rød | Input_42 | 0x25.10
7 | Entré | Ved dør til køkken | Tryk 6 tast | Tryk NH | Grå | Input_43 | 0x25.11
10 | Entré | Ved yderdør | Tryk 4 tast | GND | Blå | GND
10 | Entré | Ved yderdør | Tryk 4 tast | Tryk ØV | Sort | Input_44 | 0x25.12
10 | Entré | Ved yderdør | Tryk 4 tast | Tryk ØH | Grøn | Input_45 | 0x25.13
10 | Entré | Ved yderdør | Tryk 4 tast | Tryk NV | Violet | Input_46 | 0x25.14
10 | Entré | Ved yderdør | Tryk 4 tast | Tryk NH | Brun | Input_47 | 0x25.15
8 | Soveværelse | Ved dør til st. bad | Tryk 6 tast | GND | Blå | GND
8 | Soveværelse | Ved dør til st. bad | Tryk 6 tast | Tryk ØV | Sort | Input_48 | 0x26.0
8 | Soveværelse | Ved dør til st. bad | Tryk 6 tast | Tryk ØH | Grøn | Input_49 | 0x26.1
8 | Soveværelse | Ved dør til st. bad | Tryk 6 tast | Tryk MV | Violet | Input_50 | 0x26.2
8 | Soveværelse | Ved dør til st. bad | Tryk 6 tast | Tryk MH | Brun | Input_51 | 0x26.3
8 | Soveværelse | Ved dør til st. bad | Tryk 6 tast | Tryk NV | Rød | Input_52 | 0x26.4
8 | Soveværelse | Ved dør til st. bad | Tryk 6 tast | Tryk NH | Grå | Input_53 | 0x26.5
11 | Køkken | Ved dør til viktualrum | Tryk 6 tast | GND | Blå | GND
11 | Køkken | Ved dør til viktualrum | Tryk 6 tast | Tryk ØV | Sort | Input_54 | 0x26.6
11 | Køkken | Ved dør til viktualrum | Tryk 6 tast | Tryk ØH | Grøn | Input_55 | 0x26.7
11 | Køkken | Ved dør til viktualrum | Tryk 6 tast | Tryk MV | | Input_56 | 0x26.8
11 | Køkken | Ved dør til viktualrum | Tryk 6 tast | Tryk MH | | Input_57 | 0x26.9
11 | Køkken | Ved dør til viktualrum | Tryk 6 tast | Tryk NV | Rød | Input_58 | 0x26.10
11 | Køkken | Ved dør til viktualrum | Tryk 6 tast | Tryk NH | Grå | Input_59 | 0x26.11
33 | Stue | På væg | Pir | Alarm | Sort | Input_60 | 0x26.12
| Soveværelse | Ved dør til toilet | Pir | Alarm | Hvid | Input_61 | 0x26.13
31 | Bryggers | På væg | Pir | Alarm | Sort | Input_62 | 0x26.14

Kabel | Lokalitet | Placering____******* | Komponent | Terminal | Farve | I/O Interface | I2C- Addr
30 | Garage | På væg | Pir | Alarm | Sort | Input_63 | 0x26.15
12 | Garage | Ved yderdør | Tryk 6 tast | GND | Blå | GND
12 | Garage | Ved yderdør | Tryk 6 tast | Tryk ØV | Sort | Input_64 | 0x27.0
12 | Garage | Ved yderdør | Tryk 6 tast | Tryk ØH | Grøn | Input_65 | 0x27.1
12 | Garage | Ved yderdør | Tryk 6 tast | Tryk MV | Violet | Input_66 | 0x27.2
12 | Garage | Ved yderdør | Tryk 6 tast | Tryk MH | | Input_67 | 0x27.3
12 | Garage | Ved yderdør | Tryk 6 tast | Tryk NV | Rød | Input_68 | 0x27.4
12 | Garage | Ved yderdør | Tryk 6 tast | Tryk NH | | Input_69 | 0x27.5
| Stue | | Røgsensor | Orange | Input_70 | 0x27.6
| Soveværelse | | Røgsensor | Hvid | Input_71 | 0x27.7
36 | Bryggers | I loft | Røgsensor | Sort | Input_72 | 0x27.8

Udgang
7
02 | Violet
Garage | Røgsensor | Input_73 | 0x27.9

Udgang
7

02

Udendørs | Indkørsel | Røgsensor | Grøn | Input_74 | 0x27.10

Udgang
7
03 | HvidBlå
9 | Soveværelse | Ved seng H | Tryk 4 tast | GND | Grå | GND
9 | Soveværelse | Ved seng H | Tryk 4 tast | Tryk ØV | Rød | Input_76 | 0x27.12
9 | Soveværelse | Ved seng H | Tryk 4 tast | Tryk ØH | Hvid | Input_77 | 0x27.13
9 | Soveværelse | Ved seng H | Tryk 4 tast | Tryk NV | Orange | Input_78 | 0x27.14
9 | Soveværelse | Ved seng H | Tryk 4 tast | Tryk NH | Gul | Input_7931 | 0x27.15

Output

Lokalitet | Placering | Komponent | Farve | Kabel | Kabeltype

IHC
Modul
Adresse | Ledning
0 | Stue | Spot | Lampeudtag | -- | 208 | 2x4+2x1.5

Udgang
8
04 | Sort
1 | Stue | I loft | Lampeudtag | Hvid | 211 | 5x1.5

Udgang
4
05 | Hvid
2 | Stue | I kip | Lampeudtag | Sort | 205 | 5x1.5

Udgang
4
02 | Sort
3 | Stue | TV | Lampeudtag | Hvid | 205 | 5x1.5

Udgang
4
03 | Hvid
4 | Stue | Gulv | Stikkontakt | Brun | 103 | 5x1.5

Udgang
1
07 | Brun
5 | Entré | I loft | Lampeudtag | Brun | 206 | 5x1.5

Udgang
4
06 | Brun
6 | Entré | Gulv | Stikkontakt | Hvid | 102 | 5x1.5

Udgang
2
03 | Hvid
7 | Køkken | Spot | Lampeudtag | -- | 209 | 2x1.5

Udgang
05 | Violet

Lokalitet | Placering | Komponent | Farve | Kabel | Kabeltype

IHC
Modul
Adresse | Ledning
8 | Køkken | I loft | Lampeudtag | Sort | 205 | 5x1.5

Udgang
4
04 | Sort
9 | Køkken

Over spisebord (gl.
lysdæmp D12)
Lampeudtag | Brun | 205 | 5x1.5

Udgang
8
08 | Brun
10 | Køkken | I kip D13 | Lampeudtag | Brun | 205 | 5x1.5

Udgang
6
03 | Violet
11 | Køkken | Gulv | Stikkontakt | Hvid

101 /
102

5x1.5

Udgang
1
03 | Hvid
12 | Soveværelse | I loft | Lampeudtag | Hvid | 206 | 5x1.5

Udgang
4
08 | Hvid
13 | Soveværelse | Gulv | Stikkontakt | Sort | 103 | 5x1.5

Udgang
1
08 | Sort
14 | Soveværelse | TV | Stikkontakt | Hvid | 207 | 5x1.5

Udgang
5
03 | Hvid
15 | Værelse(8) | I loft | Lampeudtag | Sort | 201 | 5x1.5

Udgang
3
04 | Sort
16 | Værelse(8) | Gulv | Stikkontakt | Brun

101 /
104

5x1.5

Udgang
1
04 | Brun
17 | Værelse(2) | I loft | Lampeudtag | Hvid | 201 | 5x1.5

Udgang
3
05 | Hvid
18 | Værelse(2) | Gulv | Stikkontakt | Brun | 101 | 5x1.5

Udgang
1
01 | Brun
19 | Stort Bad | I loft | Lampeudtag | Brun | 207 | 5x1.5

Udgang
5
01 | Brun
20 | Stort Bad | Spot | Lampeudtag | -- | 210 | 2x4+2x1.5

Udgang
8
01 | Brun
21 | Stort Bad | Gulv | Stikkontakt | Sort | 207 | 5x1.5

Udgang
5
02 | Sort
22 | Bryggers | Spot | Lampeudtag | -- | 202 | 2x1.5

Udgang
8
02 | Brun
23 | Bryggers | På væg | Lampeudtag | Hvid | 204 | 5x1.5

Udgang
2
07 | Hvid
24 | Bryggers | Gulv | Stikkontakt | Sort

101 /
204

5x1.5

Udgang
1
02 | Sort
25 | Lille Bad | Spot | Lampeudtag | -- | 203 | 2x1.5

Udgang
8
03 | Brun
26 | Lille Bad | På væg | Lampeudtag | Brun | 107 | 5x1.5

Udgang
2
04 | Brun
27 | Lille Bad | Gulv | Stikkontakt | Sort | 107 | 5x1.5

Udgang
2
05 | Sort
28 | Garage | I loft | Lampeudtag | Sort | 200 | 5x1.5

Udgang
3
06 | Sort
29 | Garage | I loft | Lampeudtag | Hvid | 200 | 5x1.5

Udgang
07 | Hvid

Lokalitet | Placering | Komponent | Farve | Kabel | Kabeltype
Adresse | Ledning
30 | Garage | I loft Ex | Lampeudtag | Brun | 201 | 5x1.5

Udgang
3
03 | Brun
31 | Garage | Gulv | Stikkontakt | Hvid | 100 | 5x1.5

Udgang
1
06 | Hvid
32 | Garage | Gulv Ex | Stikkontakt | Sort | 100 | 5x1.5

Udgang
1
05 | Sort
33 | Viktualrum | I loft | Lampeudtag | Brun | 204 | 5x1.5

Udgang
2
06 | Brun
34 | Viktualrum | Gulv | Stikkontakt | Brun | 102 | 5x1.5

Udgang
2
02 | Brun
35 | Walkin | I loft | Lampeudtag | Sort | 206 | 5x1.5

Udgang
4
07 | Sort
36 | Walkin | Gulv | Stikkontakt | Hvid | 103 | 5x1.5

Udgang
2
01 | Hvid
37 | Walkin | Medie Center | Stikkontakt | Sort | 213 | 5x1.5

Udgang
2
08 | Sort
38 | Udendørs | På væg udv | Lampeudtag | Brun | 212 | 3x1.5

Udgang
5
04 | Brun
39 | Udendørs | Spot | Lampeudtag | Hvid | 107 | 5x1.5

Udgang
5
06 | Hvid
40 | Udendørs | Stikk ter. | Stikkontakt | Brun | 105 | 5x1.5

Udgang
3
01 | Brun
41 | Udendørs | Stikk gar. | Stikkontakt | Brun | 106 | 5x1.5

Udgang
3
02 | Brun
42 | Udendørs | I Jord Udvendig | Lampeudtag | Brun | -- | 5x1.5

Udgang
8
06 | Brun
43 | Loft | I loft | Lampeudtag | Sort | 107 | 5x1.5

Udgang
5
05 | Sort
44 | Loft | Dobbeltstik | Stikkontakt | -- | -- | 5x1.5

Udgang
3
08 | Sort
45 | Sluk Alt | Spot køk+stue | Lampeudtag | -- | -- | --

Udgang
6
02 | Grøn
46 | Magnetventil | --

Magnetventil
NO

Udgang
8
07 | Brun
47 | Køkken | Ved dør til viktualrum

Lydgiver intern
80 dB
-- | 38

IHC LINK-10 NOPOVIC
(5x2x0 6mm)

Udgang
6
05 | Sort
48 | Køkken | Ved dør til viktualrum

Lydgiver intern
102 dB
-- | 38

IHC LINK-10 NOPOVIC
(5x2x0 6mm)

Udgang
6
06 | Grøn
49 | Soveværelse | Diode | Lampeudtag | Gul | 8

IHC LINK-10 NOPOVIC
(5x2x0 6mm)

Udgang
7
04 | Gul
50 | Garage | Diode | Dørlås | -- | --

IHC LINK-10 NOPOVIC
(5x2x0 6mm)

Udgang
7
01 | Orange
51 | Udendørs | På væg udv

Lydgiver
ekstern

Sort 39

IHC LINK-10 NOPOVIC
(5x2x0 6mm)

Udgang
04 | Sort

## IHC (gammel installation)

Input og Output

LK_IHC_Control_Installationsdokumentation.pdf InputOutput.ods
InputOutput.xls

Input

Lokalitet | Placering | Komponent | Kabel | Terminal

IHC
Modul
Ledning | Farve | Forsyning | Ledning2
0 | Lille Bad | Ved dør | Tryk 4 tast | 1 | Tryk ØV

Indgang
1
01 | Sort
1 | Lille Bad | Ved dør | Tryk 4 tast | 1 | Tryk ØH

Indgang
1
02 | Grøn
2 | Lille Bad | Ved dør | Tryk 4 tast | 1 | Tryk NV

Indgang
1
03 | Violet
3 | Lille Bad | Ved dør | Tryk 4 tast | 1 | Tryk NH

Indgang
1
04 | Brun
4 | Værelse(2) | Ved dør | Tryk 4 tast | 2 | Tryk ØV

Indgang
?

5 | Værelse(2) | Ved dør | Tryk 4 tast | 2 | Tryk ØH

Indgang
1
05 | Grøn
6 | Værelse(2) | Ved dør | Tryk 4 tast | 2 | Tryk NV

Indgang
?

7 | Værelse(2) | Ved dør | Tryk 4 tast | 2 | Tryk NH

Indgang
1
06 | Brun
8 | Værelse(8) | Ved dør | Tryk 4 tast | 3 | Tryk ØV

Indgang
1
07 | Sort
9 | Værelse(8) | Ved dør | Tryk 4 tast | 3 | Tryk ØH

Indgang
?

10 | Værelse(8) | Ved dør | Tryk 4 tast | 3 | Tryk NV

Indgang
1
08 | Violet
11 | Værelse(8) | Ved dør | Tryk 4 tast | 3 | Tryk NH

Indgang
?

12 | Garage | Ved dør | Tryk 6 tast | 4 | Tryk ØV

Indgang
1
15 | Sort
13 | Garage | Ved dør | Tryk 6 tast | 4 | Tryk ØH

Indgang
1
16 | Grøn
14 | Garage | Ved dør | Tryk 6 tast | 4 | Tryk MV

Indgang
?

15 | Garage | Ved dør | Tryk 6 tast | 4 | Tryk MH

Indgang
?

16 | Garage | Ved dør | Tryk 6 tast | 4 | Tryk NV

Indgang
1
17 | Rød
17 | Garage | Ved dør | Tryk 6 tast | 4 | Tryk NH

Indgang
?

18 Køkken

Ved dør til
bryggers
Tryk 6 tast | 5 | Tryk ØV

Indgang
2
01 | Sort
19 | Køkken

Ved dør til
bryggers
Tryk 6 tast | 5 | Tryk ØH

Indgang
02 | Grøn

Lokalitet | Placering | Komponent | Kabel | Terminal
Ledning | Farve | Forsyning | Ledning2
20 | Køkken

Ved dør til
bryggers
Tryk 6 tast | 5 | Tryk MV

Indgang
2
03 | Violet
21 | Køkken

Ved dør til
bryggers
Tryk 6 tast | 5 | Tryk MH

Indgang
?

22 Køkken

Ved dør til
bryggers
Tryk 6 tast | 5 | Tryk NV

Indgang
2
04 | Rød
23 | Køkken

Ved dør til
bryggers
Tryk 6 tast | 5 | Tryk NH

Indgang
2
05 | Grå
24 | Stue | På væg | Tryk 6 tast | 6 | Tryk ØV

Indgang
2
12 | Sort
25 | Stue | På væg | Tryk 6 tast | 6 | Tryk ØH

Indgang
2
13 | Grøn
26 | Stue | På væg | Tryk 6 tast | 6 | Tryk MV

Indgang
2
14 | Violet
27 | Stue | På væg | Tryk 6 tast | 6 | Tryk MH

Indgang
?

28 | Stue | På væg | Tryk 6 tast | 6 | Tryk NV

Indgang
2
15 | Rød
29 | Stue | På væg | Tryk 6 tast | 6 | Tryk NH

Indgang
2
16 | Grå
30 | Entré

Ved dør til
køkken
Tryk 6 tast | 7 | Tryk ØV

Indgang
3
08 | Sort
31 | Entré

Ved dør til
køkken
Tryk 6 tast | 7 | Tryk ØH

Indgang
3
11 | Grøn
32 | Entré

Ved dør til
køkken
Tryk 6 tast | 7 | Tryk MV

Indgang
3
12 | Violet
33 | Entré

Ved dør til
køkken
Tryk 6 tast | 7 | Tryk MH

Indgang
3
13 | Brun
34 | Entré

Ved dør til
køkken
Tryk 6 tast | 7 | Tryk NV

Indgang
3
14 | Rød
35 | Entré

Ved dør til
køkken
Tryk 6 tast | 7 | Tryk NH

Indgang
?

36 Soveværelse

Ved dør til
st. bad
Tryk 6 tast | 8 | Tryk ØV

Indgang
3
01 | Sort
37 | Soveværelse

Ved dør til
st. bad
Tryk 6 tast | 8 | Tryk ØH

Indgang
3
02 | Grøn
38 | Soveværelse

Ved dør til
st. bad
Tryk 6 tast | 8 | Tryk MV

Indgang
3
03 | Violet
39 | Soveværelse

Ved dør til
st. bad
Tryk 6 tast | 8 | Tryk MH

Indgang
3
04 | Brun
40 | Soveværelse

Ved dør til
st. bad
Tryk 6 tast | 8 | Tryk NV

Indgang
3
05 | Rød
41 | Soveværelse

Ved dør til
st. bad
Tryk 6 tast | 8 | Tryk NH

Indgang
3
06 | Grå
42 | Soveværelse | Ved seng V | Tryk 4 tast | 9 | Tryk ØV

Indgang
01 | Sort

Lokalitet | Placering | Komponent | Kabel | Terminal
Ledning | Farve | Forsyning | Ledning2
43 | Soveværelse | Ved seng V | Tryk 4 tast | 9 | Tryk ØH

Indgang
4
02 | Grøn
44 | Soveværelse | Ved seng V | Tryk 4 tast | 9 | Tryk NV

Indgang
4
03 | Violet
45 | Soveværelse | Ved seng V | Tryk 4 tast | 9 | Tryk NH

Indgang
4
04 | Brun
46 | Soveværelse | Ved seng H | Tryk 4 tast | 9 | Tryk ØV

Indgang
4
05 | Rød
47 | Soveværelse | Ved seng H | Tryk 4 tast | 9 | Tryk ØH

Indgang
4
06 | Hvid
48 | Soveværelse | Ved seng H | Tryk 4 tast | 9 | Tryk NV

Indgang
4
07 | Orange
49 | Soveværelse | Ved seng H | Tryk 4 tast | 9 | Tryk NH

Indgang
4
08 | Gul
50 | Entré | Ved yderdør | Tryk 4 tast | 10 | Tryk ØV

Indgang
4
11 | Sort
51 | Entré | Ved yderdør | Tryk 4 tast | 10 | Tryk ØH

Indgang
4
12 | Grøn
52 | Entré | Ved yderdør | Tryk 4 tast | 10 | Tryk NV

Indgang
4
13 | Violet
53 | Entré | Ved yderdør | Tryk 4 tast | 10 | Tryk NH

Indgang
?

54 Køkken

Ved dør til
viktualrum
Tryk 6 tast | 11 | Tryk ØV

Indgang
2
06 | Sort
55 | Køkken

Ved dør til
viktualrum
Tryk 6 tast | 11 | Tryk ØH

Indgang
2
07 | Grøn
56 | Køkken

Ved dør til
viktualrum
Tryk 6 tast | 11 | Tryk MV

Indgang
?

57 Køkken

Ved dør til
viktualrum
Tryk 6 tast | 11 | Tryk MH

Indgang
?

58 Køkken

Ved dør til
viktualrum
Tryk 6 tast | 11 | Tryk NV

Indgang
2
08 | Rød
59 | Køkken

Ved dør til
viktualrum
Tryk 6 tast | 11 | Tryk NH

Indgang
2
11 | Grå
60 | Garage | Ved yderdør | Tryk 6 tast | 12 | Tryk ØV

Indgang
1
11 | Sort
61 | Garage | Ved yderdør | Tryk 6 tast | 12 | Tryk ØH

Indgang
1
12 | Grøn
62 | Garage | Ved yderdør | Tryk 6 tast | 12 | Tryk MV

Indgang
1
13 | Violet
63 | Garage | Ved yderdør | Tryk 6 tast | 12 | Tryk MH

Indgang
?

64 | Garage | Ved yderdør | Tryk 6 tast | 12 | Tryk NV

Indgang
1
14 | Rød
65 | Garage | Ved yderdør | Tryk 6 tast | 12 | Tryk NH

Indgang
?

Lokalitet | Placering | Komponent | Kabel | Terminal
Ledning | Farve | Forsyning | Ledning2
66 | Stue | Røgsensor

Indgang
4
18 | Orange | Udgang 7 | 02
67 | Soveværelse | Røgsensor

Indgang
2
18 | Hvid | Udgang 7 | 02
68 | Bryggers | I loft | Røgsensor | 36

Indgang
3
07 | Sort | Udgang 7 | 02 | Violet
69 | Garage | Røgsensor

Indgang
4
17 | Udgang 7 | 02
70 | Udendørs | Indkørsel | Røgsensor

Indgang
5
Grøn | Udgang 7 | 03 | HvidBlå
71 | Stue | På væg | Pir | 33 | Alarm

Indgang
3
18 | Sort
72 | Soveværelse

Ved dør til
toilet
Pir | Tilstede

Indgang
5
08 | Hvid
73 | Bryggers | På væg | Pir | 31 | Alarm

Indgang
3
16 | Sort
74 | Garage | På væg | Pir | 30 | Alarm

Indgang
3
15 | Sort

Output

Lokalitet | Placering | Komponent | Farve | Kabel | Kabeltype

IHC
Modul
Adresse | Ledning
0 | Stue | Spot | Lampeudtag | -- | 208 | 2x4+2x1.5

Udgang
8
04 | Sort
1 | Stue | I loft | Lampeudtag | Hvid | 211 | 5x1.5

Udgang
4
05 | Hvid
2 | Stue | I kip | Lampeudtag | Sort | 205 | 5x1.5

Udgang
4
02 | Sort
3 | Stue | TV | Lampeudtag | Hvid | 205 | 5x1.5

Udgang
4
03 | Hvid
4 | Stue | Gulv | Stikkontakt | Brun | 103 | 5x1.5

Udgang
1
07 | Brun
5 | Entré | I loft | Lampeudtag | Brun | 206 | 5x1.5

Udgang
4
06 | Brun
6 | Entré | Gulv | Stikkontakt | Hvid | 102 | 5x1.5

Udgang
2
03 | Hvid
7 | Køkken | Spot | Lampeudtag | -- | 209 | 2x1.5

Udgang
8
05 | Violet
8 | Køkken | I loft | Lampeudtag | Sort | 205 | 5x1.5

Udgang
4
04 | Sort
9 | Køkken

Over spisebord (gl.
lysdæmp D12)
Lampeudtag | Brun | 205 | 5x1.5

Udgang
8
08 | Brun
10 | Køkken | I kip D13 | Lampeudtag | Brun | 205 | 5x1.5

Udgang
6
03 | Violet
11 | Køkken | Gulv | Stikkontakt | Hvid

101 /
5x1.5

Udgang
03 | Hvid

Lokalitet | Placering | Komponent | Farve | Kabel | Kabeltype
Adresse | Ledning
12 | Soveværelse | I loft | Lampeudtag | Hvid | 206 | 5x1.5

Udgang
4
08 | Hvid
13 | Soveværelse | Gulv | Stikkontakt | Sort | 103 | 5x1.5

Udgang
1
08 | Sort
14 | Soveværelse | TV | Stikkontakt | Hvid | 207 | 5x1.5

Udgang
5
03 | Hvid
15 | Værelse(8) | I loft | Lampeudtag | Sort | 201 | 5x1.5

Udgang
3
04 | Sort
16 | Værelse(8) | Gulv | Stikkontakt | Brun

101 /
104

5x1.5

Udgang
1
04 | Brun
17 | Værelse(2) | I loft | Lampeudtag | Hvid | 201 | 5x1.5

Udgang
3
05 | Hvid
18 | Værelse(2) | Gulv | Stikkontakt | Brun | 101 | 5x1.5

Udgang
1
01 | Brun
19 | Stort Bad | I loft | Lampeudtag | Brun | 207 | 5x1.5

Udgang
5
01 | Brun
20 | Stort Bad | Spot | Lampeudtag | -- | 210 | 2x4+2x1.5

Udgang
8
01 | Brun
21 | Stort Bad | Gulv | Stikkontakt | Sort | 207 | 5x1.5

Udgang
5
02 | Sort
22 | Bryggers | Spot | Lampeudtag | -- | 202 | 2x1.5

Udgang
8
02 | Brun
23 | Bryggers | På væg | Lampeudtag | Hvid | 204 | 5x1.5

Udgang
2
07 | Hvid
24 | Bryggers | Gulv | Stikkontakt | Sort

101 /
204

5x1.5

Udgang
1
02 | Sort
25 | Lille Bad | Spot | Lampeudtag | -- | 203 | 2x1.5

Udgang
8
03 | Brun
26 | Lille Bad | På væg | Lampeudtag | Brun | 107 | 5x1.5

Udgang
2
04 | Brun
27 | Lille Bad | Gulv | Stikkontakt | Sort | 107 | 5x1.5

Udgang
2
05 | Sort
28 | Garage | I loft | Lampeudtag | Sort | 200 | 5x1.5

Udgang
3
06 | Sort
29 | Garage | I loft | Lampeudtag | Hvid | 200 | 5x1.5

Udgang
3
07 | Hvid
30 | Garage | I loft Ex | Lampeudtag | Brun | 201 | 5x1.5

Udgang
3
03 | Brun
31 | Garage | Gulv | Stikkontakt | Hvid | 100 | 5x1.5

Udgang
1
06 | Hvid
32 | Garage | Gulv Ex | Stikkontakt | Sort | 100 | 5x1.5

Udgang
1
05 | Sort
33 | Viktualrum | I loft | Lampeudtag | Brun | 204 | 5x1.5

Udgang
06 | Brun

Lokalitet | Placering | Komponent | Farve | Kabel | Kabeltype
Adresse | Ledning
34 | Viktualrum | Gulv | Stikkontakt | Brun | 102 | 5x1.5

Udgang
2
02 | Brun
35 | Walkin | I loft | Lampeudtag | Sort | 206 | 5x1.5

Udgang
4
07 | Sort
36 | Walkin | Gulv | Stikkontakt | Hvid | 103 | 5x1.5

Udgang
2
01 | Hvid
37 | Walkin | Medie Center | Stikkontakt | Sort | 213 | 5x1.5

Udgang
2
08 | Sort
38 | Udendørs | På væg udv | Lampeudtag | Brun | 212 | 3x1.5

Udgang
5
04 | Brun
39 | Udendørs | Spot | Lampeudtag | Hvid | 107 | 5x1.5

Udgang
5
06 | Hvid
40 | Udendørs | Stikk ter. | Stikkontakt | Brun | 105 | 5x1.5

Udgang
3
01 | Brun
41 | Udendørs | Stikk gar. | Stikkontakt | Brun | 106 | 5x1.5

Udgang
3
02 | Brun
42 | Udendørs | I Jord Udvendig | Lampeudtag | Brun | -- | 5x1.5

Udgang
8
06 | Brun
43 | Loft | I loft | Lampeudtag | Sort | 107 | 5x1.5

Udgang
5
05 | Sort
44 | Loft | Dobbeltstik | Stikkontakt | -- | -- | 5x1.5

Udgang
3
08 | Sort
45 | Sluk Alt | Spot køk+stue | Lampeudtag | -- | -- | --

Udgang
6
02 | Grøn
46 | Magnetventil | --

Magnetventil
NO

Udgang
8
07 | Brun
47 | Køkken | Ved dør til viktualrum

Lydgiver intern
80 dB
-- | 38

IHC LINK-10 NOPOVIC
(5x2x0 6mm)

Udgang
6
05 | Sort
48 | Køkken | Ved dør til viktualrum

Lydgiver intern
102 dB
-- | 38

IHC LINK-10 NOPOVIC
(5x2x0 6mm)

Udgang
6
06 | Grøn
49 | Soveværelse | Diode | Lampeudtag | Gul | 8

IHC LINK-10 NOPOVIC
(5x2x0 6mm)

Udgang
7
04 | Gul
50 | Garage | Diode | Dørlås | -- | --

IHC LINK-10 NOPOVIC
(5x2x0 6mm)

Udgang
7
01 | Orange
51 | Udendørs | På væg udv

Lydgiver
ekstern

Sort 39

IHC LINK-10 NOPOVIC
(5x2x0 6mm)

Udgang
6
04 | Sort

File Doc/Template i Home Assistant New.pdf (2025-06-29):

## Template i Home Assistant

# Configuration:

## Configuration.yaml

# Loads default set of integrations. Do not remove. default_config:

# Load frontend themes from the themes folder frontend:

themes: !include_dir_merge_named themes

# Splitting up the configuration

# https://www.home-assistant.io/docs/configuration/splitting_configuration/#advanced-usage # Lazy Tech Geek:

# | https://youtu.be/8NnOhWuupEE

# | https://youtu.be/bj8H2yghvtU

# DrZzs & GrZzs

# https://youtu.be/FfjSA2o_0KA

automation: !include automations.yaml script: !include scripts.yaml scene: !include scenes.yaml

# !include_dir_list

# !include_dir_named

#!include_dir_merge_list

#script: !include_dir_merge_list config/scripts

template: !include_dir_merge_list config/templates

#!include_dir_merge_named

# input_number: !include_dir_merge_named config/input_number # input_text: !include_dir_merge_named config/ input_text

# input_boolean: !include_dir_merge_named config/input_boolean

recorder:
db_url: !secret maria_db

# Group:

Name | : highnrswitch
Show as | : Switch
Entity_ID | : switch.highnrswitch
Group Members | :
IHC1 Output_40
IHC1 Output_41
IHC1 Output_42
IHC1 Output_43
IHC1 Output_44
IHC1 Output_45
IHC1 Output_46
IHC1 Output_47
IHC1 Output_48
IHC1 Output_49

## Side 1 af 6

# Template:

## config/templates/LK-PushButtons.yaml

## Trigger delen:

- trigger:
- trigger: state
entity_id:
- binary_sensor.ihc1_input_00 to: "off"
id: Input_00K
from: "on"
variables:
type_id: switch
action_id: switch.toggle
target_ent: switch.ihc1_output_00
- trigger: state
entity_id:
- binary_sensor.ihc1_input_00 to: "on"
id: Input_00L
for:
hours: 0
minutes: 0
seconds: 1
variables:
type_id: switch
action_id: switch.turn_off target_ent: switch.ihc1_output_00
- trigger: state
entity_id:
- binary_sensor.ihc1_input_08 to: "off"
id: Input_08K
from: "on"
variables:
type_id: switch
action_id: switch.turn_on
target_ent: switch.ihc1_output_08
- trigger: state
entity_id:
- binary_sensor.ihc1_input_08 to: "on"
id: Input_08L
for:
hours: 0
minutes: 0
seconds: 1
variables:
type_id: switch
action_id: switch.turn_off target_ent: switch.ihc1_output_08

## Side 2 af 6

- trigger: state
entity_id:
- binary_sensor.ihc1_input_16 to: "off"
id: Input_16K
from: "on"
variables:
type_id: scene
action_id: switch.turn_on
target_ent: switch.highnrswitch
- trigger: state
entity_id:
- binary_sensor.ihc1_input_16 to: "on"
id: Input_16L
for:
hours: 0
minutes: 0
seconds: 1
variables:
type_id: scene
action_id: switch.turn_off target_ent: switch.highnrswitch
- trigger: state
entity_id:
- binary_sensor.ihc1_input_24 to: "off"
id: Input_24K
from: "on"
variables:
type_id: switch
action_id: switch.toggle
target_ent: switch.ihc1_output_24
- trigger: state
entity_id:
- binary_sensor.ihc1_input_24 to: "on"
id: Input_24L
for:
hours: 0
minutes: 0
seconds: 1
variables:
type_id: switch
action_id: switch.turn_off target_ent: switch.ihc1_output_24

## Condition delen:

condition:
- condition: or
conditions:
- condition: and
conditions:
- condition: template
value_template: >-
{{ trigger.to_state.last_updated -trigger.from_state.last_updated < as_timedelta("00:00:01") }}
- condition: template
value_template: "{{ trigger.to_state.state == 'off'}}"
- condition: and
conditions:
- condition: template
value_template: >-
{{ trigger.to_state.last_updated -trigger.from_state.last_updated >= as_timedelta("00:00:01") }}
- condition: template
value_template: "{{ trigger.to_state.state == 'on'}}"

## Side 3 af 6

## Sensor delen:

sensor:
- name: LK-Pushbutton-Pressed
state: "{{ trigger.id }},{{now().strftime('%H:%M:%S')}}" attributes:
trigger-id: "{{ trigger.id }}"
type_map: "{{ type_id: }}"
action-map: "{{ action_id }}" target-map: "{{ target_ent }}"

## Side 4 af 6

# Automations:

alias: test22
description: ""
triggers:
- trigger: state
entity_id:
- sensor.lk_pushbutton_pressed
conditions: []
actions:
- action: "{{ state_attr('sensor.lk_pushbutton_pressed','action-map') }}" metadata: {}
data: {}
target:
entity_id: "{{ state_attr('sensor.lk_pushbutton_pressed','target-map') }}" mode: single

## Side 5 af 6

# Løsninger:

Kilde: https://community.home-assistant.io/t/template-sensor-with-attributes-how-can-i-re-use-a-variable/483814/8 (https://community.home-assistant.io/t/template-sensor-with-attributes-how-can-i-re-use-a-variable/483814/8)
I am not sure if the following information will help with your project but a Trigger-based Template Sensor can have a variables section.
Any variables you define in that section can be referenced in the Sensor’s state and its attributes.

## Example

The following (contrived) example defines four variables in the variables section. The variables are then referenced in state and in the color, and level attributes.

- trigger:
- trigger: state
entity_id: sensor.demo
variables:
my_map:
10: blue
20: green
30: yellow
40: orange
50: red
60: purple
nmbr: "{{ trigger.to_state.state | int(0) }}"
rounded_nmbr: "{{ (nmbr / 10) | round(0) * 10 }}"
yes_or_no: "{{ iif(nmbr > 0, 'Yes', 'No') }}" sensor:
- name: Example
state: "{{ yes_or_no }}"
attributes:
color: "{{ my_map.get(rounded_nmbr, 'unknown') }}" level: "{{ nmbr }}"

## Didgeridrew

In addition to Taras’ response above, you can also set variables that are specific to each trigger if you

## prefer to organize it that way:

- trigger:
- id: Input_00K
trigger: state
entity_id:
- binary_sensor.ihc1_input_00 to: "off"
from: "on"
variables:
action_id: switch.toggle
target_ent: switch.ihc1_output_00
- id: Input_00L
trigger: state
entity_id:
- binary_sensor.ihc1_input_00 to: "on"
from: "off"
variables:
action_id: switch.turn_off target_ent: switch.ihc1_output_01 ...

sensor:
- name: LK-Pushbutton-Pressed
state: "{{ trigger.id }},{{now().strftime('%H:%M:%S')}}" attributes:
trigger-id: "{{ trigger.id }}"
lk-key-map: "{{ [action_id, target_ent] }}"

## Side 6 af 6

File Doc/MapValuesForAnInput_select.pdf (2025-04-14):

Map values for an input_select? (https://community.home-assistant.io/t/map-values-for-an-input-select/94354)

Kilde: https://community.home-assistant.io/t/map-values-for-an-input-select/94354/4https://community.home-assistant.io/u/petro/summary

## Ok, so everything he has is what you would use if I read his

post properly.

- id: set_motion_sensitivity trigger:
[some_trigger]
action:
service: rest_command.hue_command data_template:
command: config
data:
sensitivity: >
{{states('input_select.set_hue_sensitity')}} id: >
{% set mapper =
{ 'Laundry':'22',
'Dining table':'52',
'Auditorium':'44',
'Frontdoor':'60',
'Dorm':'56',
'Corridor':'5',
'Corridor terrace':'33',
'Master bedroom':'48',
'Corridor Office':'28',
'Control room':'7',
'Attic':'12' } %}
{% set state = states('input_select.select_hue_motion_sensor') %} {% set id = mapper[state] if state in mapper %}
{{id}}
type: sensors

Side 1 af 5

## or you could create a template sensor that updates and just

has the number.

sensor:
- platform: template
sensors:
hue_map:
value_template: >
{% set mapper =
{ 'Laundry':'22',
'Dining table':'52',
'Auditorium':'44',
'Frontdoor':'60',
'Dorm':'56',
'Corridor':'5',
'Corridor terrace':'33',
'Master bedroom':'48',
'Corridor Office':'28',
'Control room':'7',
'Attic':'12' } %}
{% set state = states('input_select.select_hue_motion_sensor') %} {% set id = mapper[state] if state in mapper %}
{{ id }}

## automation:

- id: set_motion_sensitivity trigger:
[some_trigger]
action:
service: rest_command.hue_command data_template:
command: config
data:
sensitivity: >
{{ states('input_select.set_hue_sensitity') }} id: >
{{ states('sensor.hue_map') }}
type: sensors

Side 2 af 5

## Template editor:

{% set my_test_json = { "items": ["car","horse"] } %} * Items:{% for item in my_test_json["items"] %}
* {{item}}
{%- endfor %}

* Items[0]:
* {{my_test_json["items"][0]}}

* Items[1]:
* {{my_test_json["items"][1]}}

## Result:

* Items:
* car
* horse

* Items[0]:
* car

* Items[1]:
* horse

Side 3 af 5

Kilde: https://community.home-assistant.io/t/trigger-id/443723

## Hi All (https://community.home-assistant.io/u/rossk)

Am I being really stupid here (probably as its been a long day) but for the life of me I cant seem to get this to work, or in fact even confirm it should:

## PARTIAL AUTOMATION:

trigger:
- device_id: df9b3ff7a16e7d73a89b3eadbf63b861 domain: hue
platform: device
type: long_release
subtype: 4
unique_id: 850d897b-294c-4ede-b889-b3fa964104ee id: kitchen

action:
- service: switch.turn_off
data: {}
target:
entity_id: switch.{{ trigger_id }}_motion_sensor_motion
I have tried qoutes and no qoutes and constantly get the following results:

Template rendered invalid entity IDs: switch._motion_sensor_motion

## What blindingly obvious am I missing here?

PS. I dont normally trigger off of devices but I was just testing and will likely end up using the hue event once I have worked out why I am failing at the first hurdle.
TIA
Solved by Rob (https://community.home-assistant.io/u/calisro) in post #13 (https://community.home-assistant.io/t/trigger-id/443723/13)

## Your code:

entity_id: switch.{{ trigger_id }}_motion_sensor_motion

## But… You still have the wrong thing there. It should be

entity_id: switch.{{ trigger.id }}_motion_sensor_motion

Side 4 af 5

Issues with Template sensors and mapping (https://community.home-assistant.io/t/issues-with-template-sensors-and-mapping/368843)

Kilde: https://community.home-assistant.io/t/issues-with-template-sensors-and-mapping/368843 calypso (https://community.home-assistant.io/u/calypso)
Dec 2021 (https://community.home-assistant.io/t/issues-with-template-sensors-and-mapping/368843?u=sekt1953)
So my inverter states its state numerically. I would like to map those values to a word. I have attempted to follow what I can find online but I am not coming right nor can I find official documentation on this.
- platform: template
sensors:
multiplus_inverter_state:
friendly_name: "Inverter State" unit_of_measurement: "State"
entity_id: sensor.multiplus_inverter_state_numeric value_template: >-
{% set mapper = {
'0' : 'Off',
'1' : 'Low Power',
'2' : 'Fault',
'3' : 'Bulk',
'4' : 'Absorbtion',
'5' : 'Float',
'6' : 'Storage',
'7' : 'Equalize',
'8' : 'Passthru',
'9' : 'Inverting',
'10' : 'Power Assist',
'11' : 'Power Supply',
'252' : 'Bulk Protection' } %}
{% set state = states.sensor.multiplus_inverter_state_numeric %} {{ mapper[state] if state in mapper else 'Unknown' }}
Any idea why this doesn’t work?

Solved by Petro (https://community.home-assistant.io/t/issues-with-template-sensors-and-mapping/368843) in post #13 (https://community.home-assistant.io/t/issues-with-template-sensors-and-mapping/368843/13)

{% set state = states('sensor.multiplus_inverter_state_numeric') %} {{ mapper[state] if state in mapper else 'Unknown' }}
Remove that. Your dictionary (what you cal mapper) uses umbers that are wrapped in quotes. That means they aren’t actually numbers but strings. So he mapper will fail. You want to keep your state a string, I.e. remove the int cast

Side 5 af 5

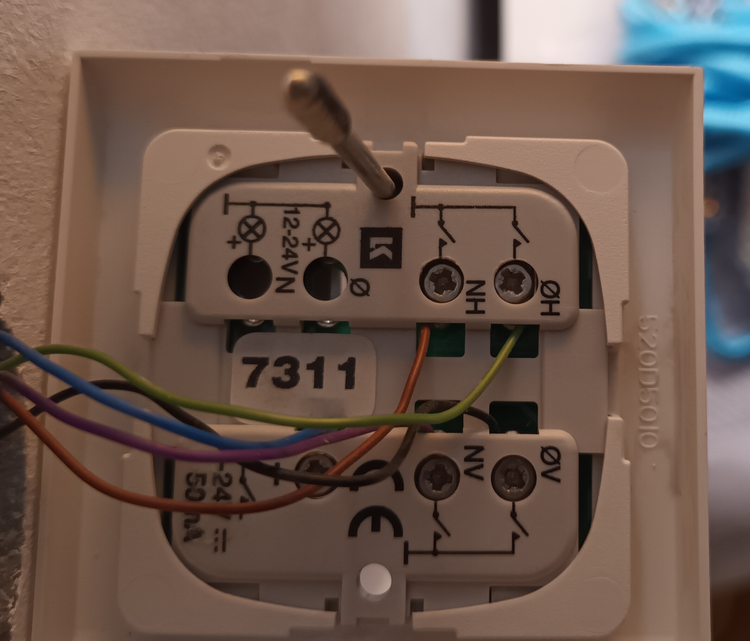
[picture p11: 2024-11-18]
Doc/Images/LK-Tryk.png

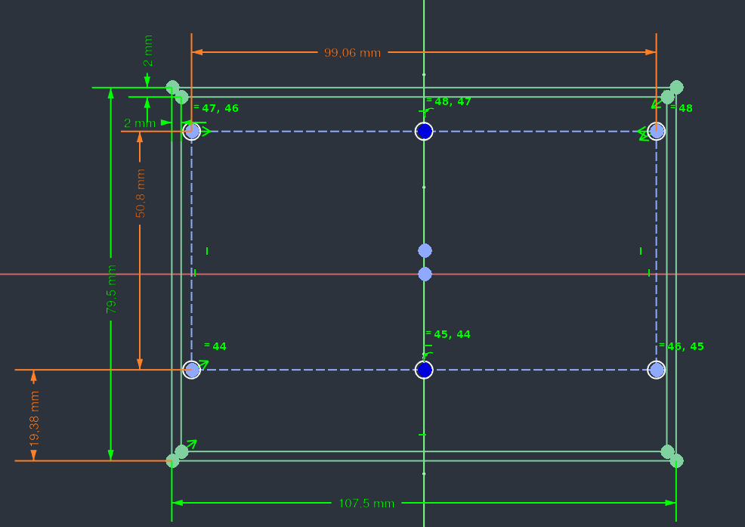
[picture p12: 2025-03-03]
FreeCAD/Images/DinBox_100-Bottom-DimentionXY.png

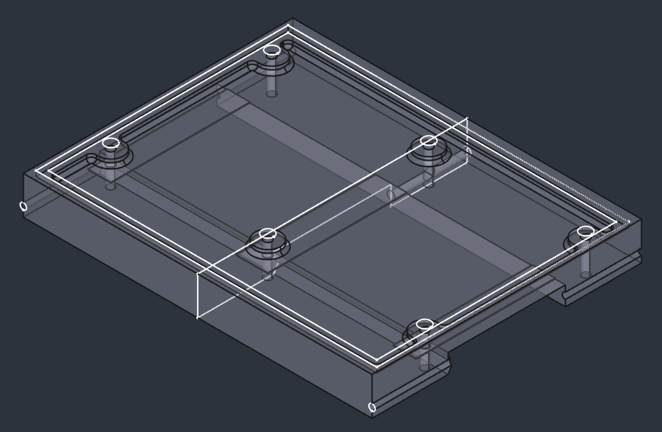
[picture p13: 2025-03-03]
FreeCAD/Images/DinBox_100-Bottom.png

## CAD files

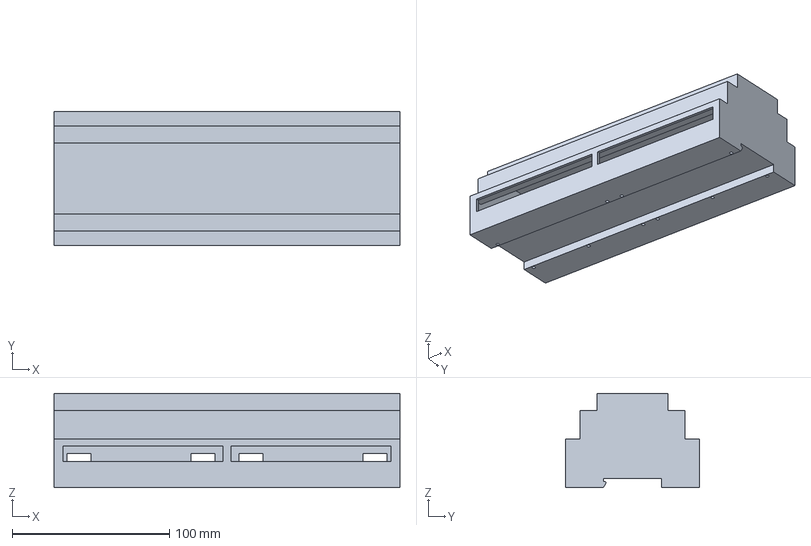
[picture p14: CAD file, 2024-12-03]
FreeCAD/Base_002.FCStd
219.9 x 85.0 x 60.0 mm

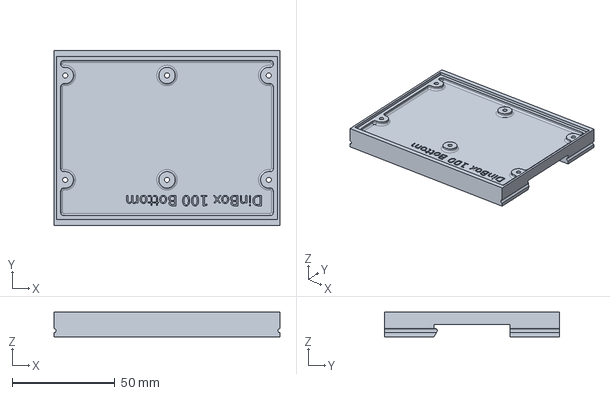
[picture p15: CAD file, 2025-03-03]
FreeCAD/DinBox/DinBox_100/DinBox_100.FCStd
110.0 x 85.0 x 12.0 mm

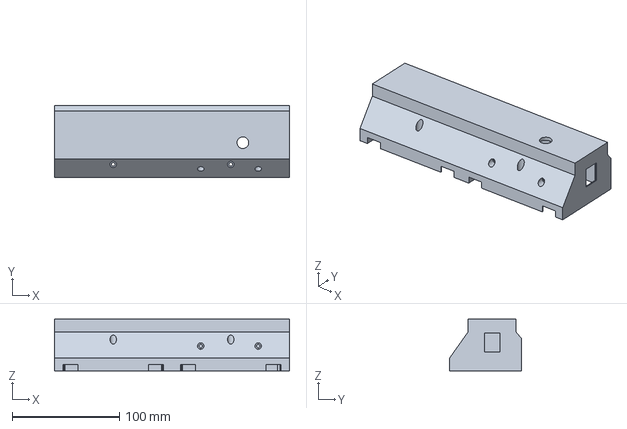
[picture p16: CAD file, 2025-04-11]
FreeCAD/DinBox/DinBox_200/DinBox_202.FCStd
219.0 x 66.8 x 48.0 mm

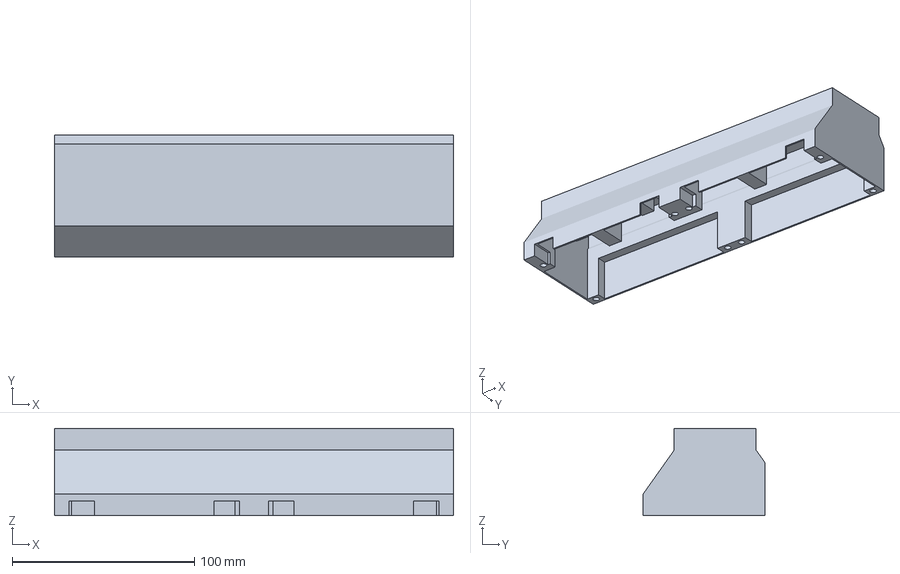
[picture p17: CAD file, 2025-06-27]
FreeCAD/DinBox/DinBox_211/DinBox_211-Body_TopPartPocket010.3mf
219.0 x 66.8 x 48.0 mm

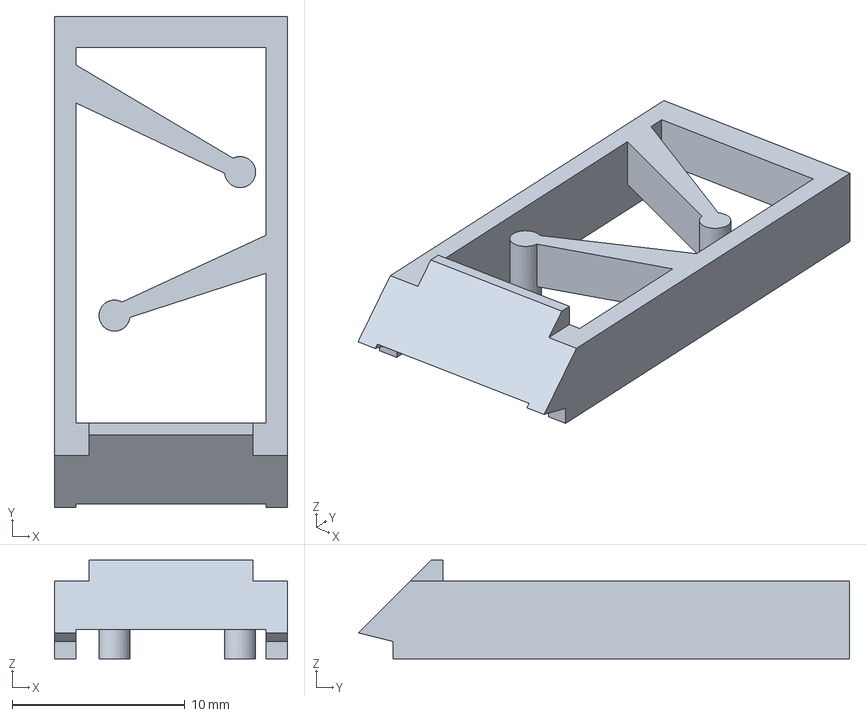
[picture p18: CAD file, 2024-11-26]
FreeCAD/Lock/Lock_01-Body.3mf
13.5 x 28.4 x 5.70 mm

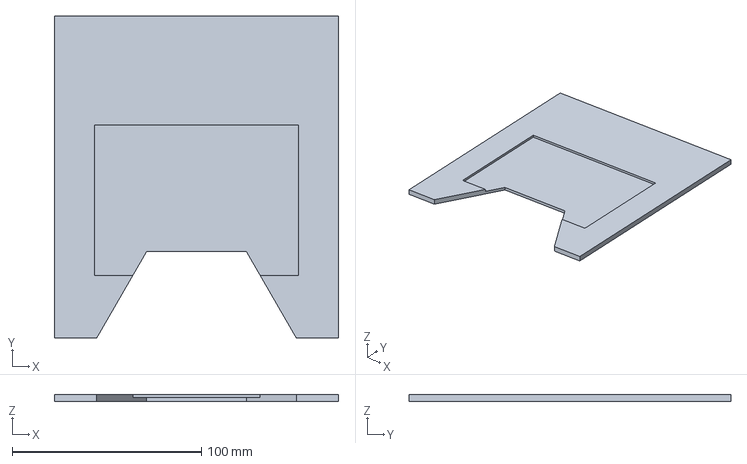
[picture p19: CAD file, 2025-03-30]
FreeCAD/SolderBay/SolderBay.FCStd
150.0 x 170.0 x 3.60 mm

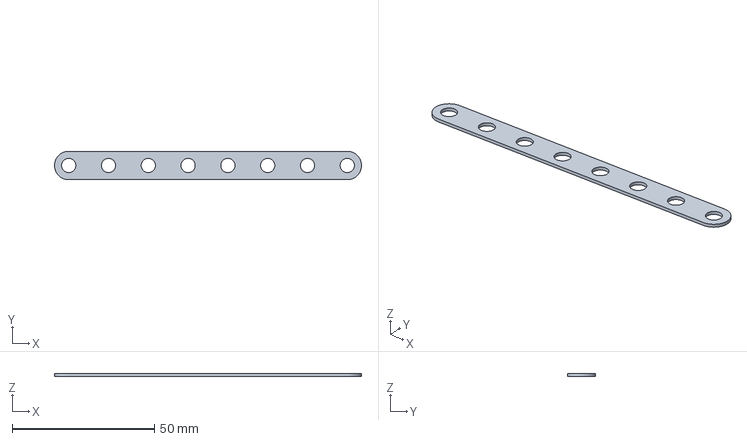
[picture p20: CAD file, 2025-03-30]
FreeCAD/TrykHolder/Trykholder_led-Body.3mf
108.0 x 10.0 x 1.00 mm

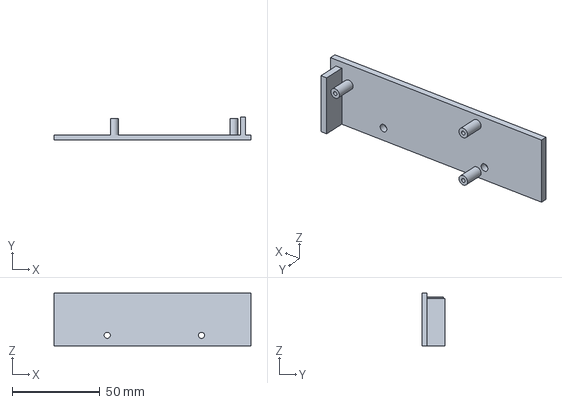
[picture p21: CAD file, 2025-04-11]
FreeCAD/DinBox/DinBox_200/DinBox_202-MCU.3mf
112.0 x 13.2 x 30.0 mm

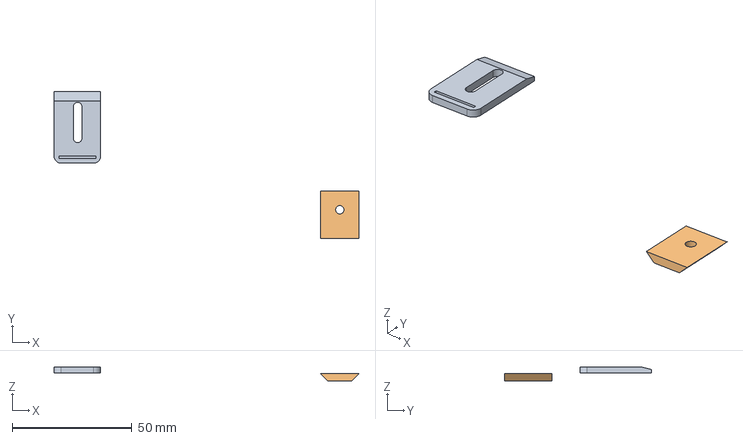
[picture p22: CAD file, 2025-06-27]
FreeCAD/DinBox/DinBox_211/DinBox_211.FCStd
127.3 x 61.5 x 5.75 mm
Body_LockPart1
Body_lockPart2

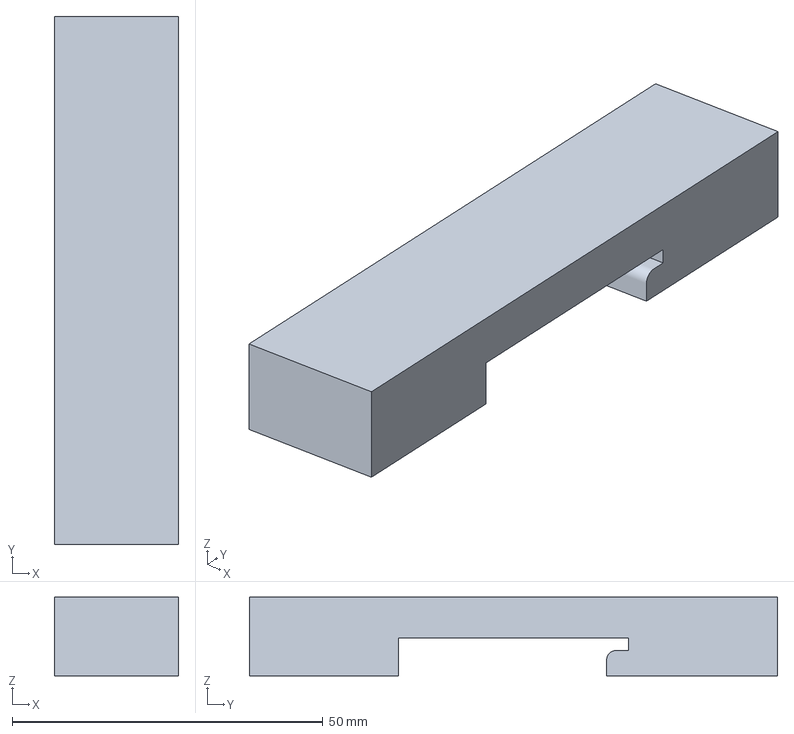
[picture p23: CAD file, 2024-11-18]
FreeCAD/Base-BodyPad.3mf
20.0 x 85.0 x 12.7 mm

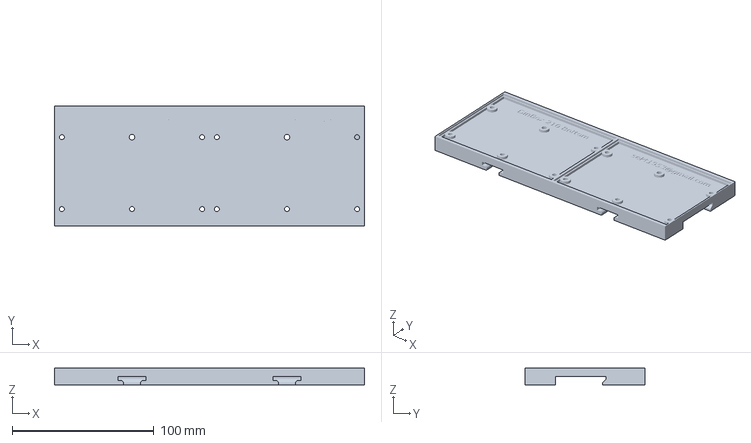
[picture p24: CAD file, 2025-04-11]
FreeCAD/DinBox/DinBox_200/DinBox_210-Body-Bottom.3mf
219.0 x 85.0 x 12.0 mm

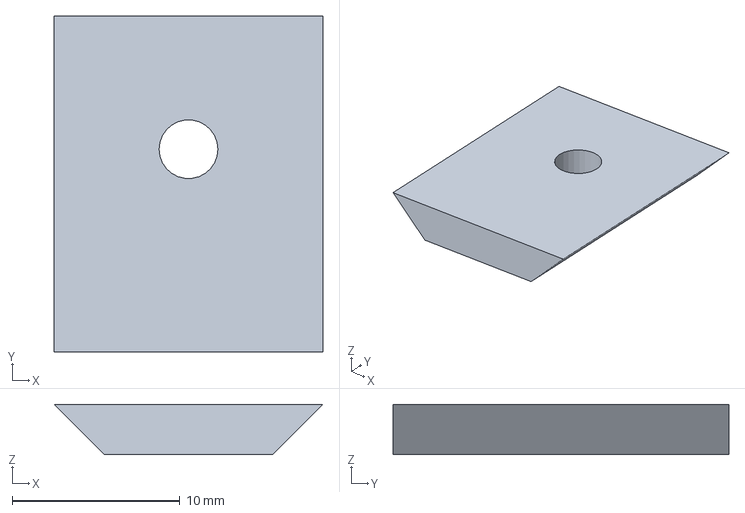
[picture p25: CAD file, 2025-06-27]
FreeCAD/DinBox/DinBox_211/DinBox_211-Body_lockPart2.3mf
16.0 x 20.0 x 3.00 mm

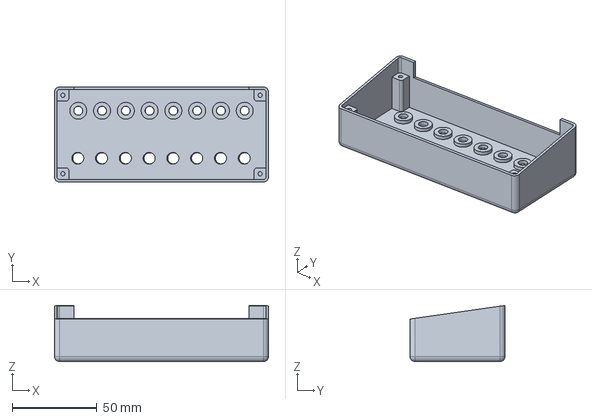
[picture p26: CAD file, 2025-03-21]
FreeCAD/TrykHolder/Trykholder_v4.FCStd
126.0 x 56.0 x 33.0 mm

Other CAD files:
FreeCAD/DinBox/DinBox_100/DinBox_100-Bottom.3mf
FreeCAD/DINBox_002.FCStd
FreeCAD/Lock/Lock_01.FCStd
FreeCAD/SolderBay/SolderBay-Body.3mf
FreeCAD/TrykHolder/Trykholder_led.FCStd
FreeCAD/Base-Body.3mf
FreeCAD/Base-Body001.3mf
FreeCAD/Base.FCStd
FreeCAD/DinBox/DinBox_200/DinBox_200-Body002.3mf
FreeCAD/DinBox/DinBox_200/DinBox_200-Top.3mf
FreeCAD/DinBox/DinBox_200/DinBox_200.FCStd
FreeCAD/DinBox/DinBox_200/DinBox_201-Body.3mf
FreeCAD/DinBox/DinBox_200/DinBox_201-MCU.3mf
FreeCAD/DinBox/DinBox_200/DinBox_201.FCStd
FreeCAD/DinBox/DinBox_200/DinBox_202-Body.3mf
FreeCAD/DinBox/DinBox_200/DinBox_210-Body-Lock.3mf
FreeCAD/DinBox/DinBox_200/Unnamed1-Body.3mf
FreeCAD/DinBox/DinBox_211/DinBox_211-Body-Lock.3mf
FreeCAD/DinBox/DinBox_211/DinBox_211-Body_TopPart.3mf
FreeCAD/DinBox/DinBox_211/DinBox_211-Body_TopPartPad005.3mf
FreeCAD/DinBox/DinBox_211/DinBox_211-Body_bottomPart.3mf
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

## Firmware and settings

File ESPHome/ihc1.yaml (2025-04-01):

substitutions:
  esphome_name: "ihc1"
  esphome_friendly_name: "IHC1"

# PCA9685 Kilde: https://esphome.io/components/output/pca9685
# id (Optional, ID): 
#   The id to use for this pca9685 component. 
#   Use this if you have multiple PCA9685s connected at the same time
  id_pca9685: "pca9685_hub"
  
# frequency (Optional, float): 
#   The frequency to let the component drive all PWM outputs at. 
#   Must be in range from 24Hz to 1525.88Hz. Default 1000Hz.  
  frequency_pca9685: 1000Hz

# Light Transition length
  light_default_transition: "0s"
  light_flash_transition: "0s"

# PCF8574N & PCF8575
# 8bit portudvidelse I2C (2 wire) interface DIL16 Adresserbar til 
  id_pcf8574: "pcf8574_hub"

# MCP23017
# 8bit portudvidelse I2C (2 wire) interface DIL16 Adresserbar til 
  id_mcp23017: "mcp23017_hub"

# Delay before track occupied on/off
  track_delayed_on: 12ms
  track_delayed_off: 10ms

# Delay before junction_switch on/off
  junction_switch_delayed_on: 10ms
  junction_switch_delayed_off: 10ms

# I2C Port settings  
  i2c_sda: "21"
  i2c_scl: "22"
  i2c_scan: "true"
  i2c_id: "bus_a"
  i2c_frequency: "10kHz"

# ESP32 base config
<<: !include ./Includes/ESP32/.olimex-esp32-poe.yaml

# I/O Card
<<: !include ./Includes/Finn/.mcp23017_ids.yaml
<<: !include ./Includes/Finn/.mcp23017_output.yaml
<<: !include ./Includes/Finn/.mcp23017_input.yaml

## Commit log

2024-11-18 Finder Relays
2024-11-26 input output
    [Alarm.csv, Datalinie indgange.csv, Import1.csv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]
2024-12-01 pcb 020
    [Input_Board_020.fzz]
2024-12-01 pcb 020a
2024-12-03 dinbox 002
    [Base_002.FCStd, DINBox_002.FCStd, Input_Board_010.fzz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]
2025-02-10 print send 20250210
    [CPU_Board_021.fzz, Input_Board_020.fzz, Input_Board_021.fzz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]
2025-03-14 esp32 update
2025-03-30 esphome file updsate
    [Input_Board_030.fzz, SolderBay-Body.3mf, SolderBay.FCStd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]
2025-04-04 DinBox 200
    [DinBox_100-Bottom.3mf, DinBox_100.FCStd, DinBox_200-Body002.3mf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]
2025-04-04 dinbox 201
    [DinBox_200-Top.3mf, DinBox_200.FCStd, DinBox_201.FCStd]
2025-04-07 DinBox 202
    [DinBox_201-Body.3mf, DinBox_201-MCU.3mf, DinBox_201.FCStd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]
2025-04-11 OTA enabled
    [DinBox_202-Body.3mf, DinBox_202-MCU.3mf, DinBox_202.FCStd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]
2025-04-14 script for trykkanpper
    [DinBox_211-Body-Lock.3mf, DinBox_211-Body_TopPart.3mf, DinBox_211-Body_TopPartPad005.3mf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]
2025-04-14 sensor map
2025-06-27 ny installation Doc
    [DinBox_211-Body_TopPartPocket010.3mf, DinBox_211-Body_lockPart2.3mf, DinBox_211.FCStd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]
